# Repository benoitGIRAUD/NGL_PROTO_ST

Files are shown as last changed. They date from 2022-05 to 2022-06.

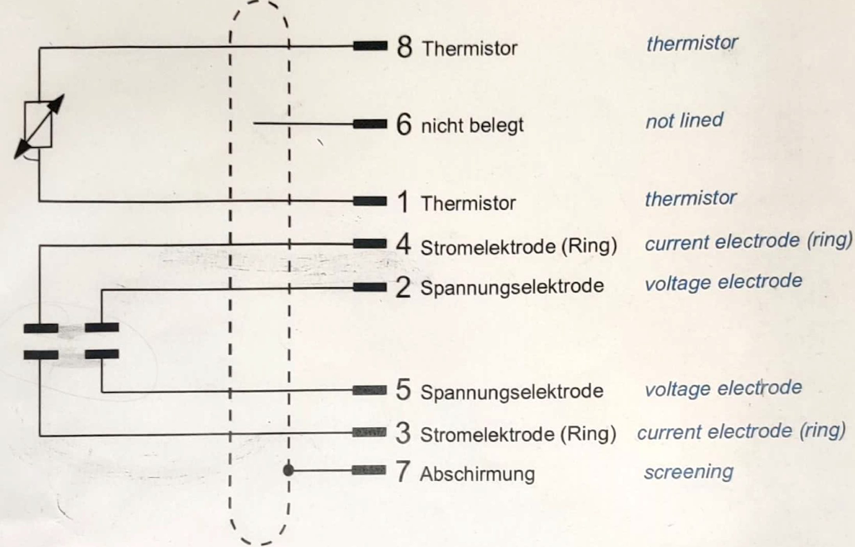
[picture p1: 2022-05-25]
Doc/8DIN.png

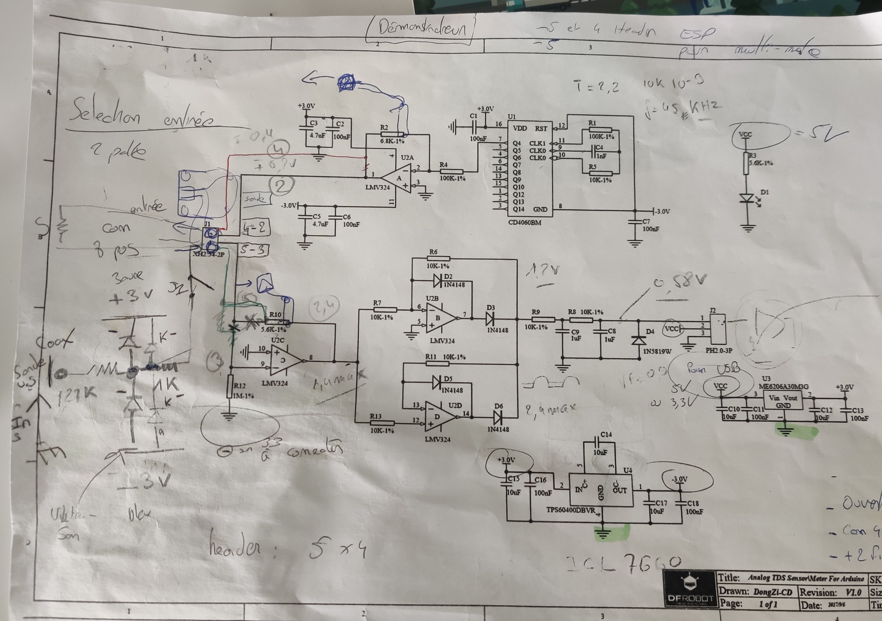
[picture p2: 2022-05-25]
Doc/Schéma_fullAnoté.jpg

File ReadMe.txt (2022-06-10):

2 CHEMIN à rajouter:

LIBNGL
LIBNGL3D

LIBNGL
LIBNGLST
C:\Users\b.giraud-missier.WKS-TH-BE-03\Documents\Git\NGL_PROTO_ST\Lib_NGL_Proto

${LIBNGL}

Mettre le chemin du dossier de Librairie NGL dans LIBNGL:(le début du chemin diffère selon PC)

Ex:
C:\Users\b.giraud-missier.WKS-TH-BE-03\Documents\Git\NGL_Proto\Lib_NGL_Proto\Lib_NGL_Proto.pretty

Et Mettre le chemin du dossier de Librairie NGL dans LIBNGL3D: (le début du chemin diffère selon PC)

Ex:
C:\Users\b.giraud-missier.WKS-TH-BE-03\Documents\Git\NGL_Proto

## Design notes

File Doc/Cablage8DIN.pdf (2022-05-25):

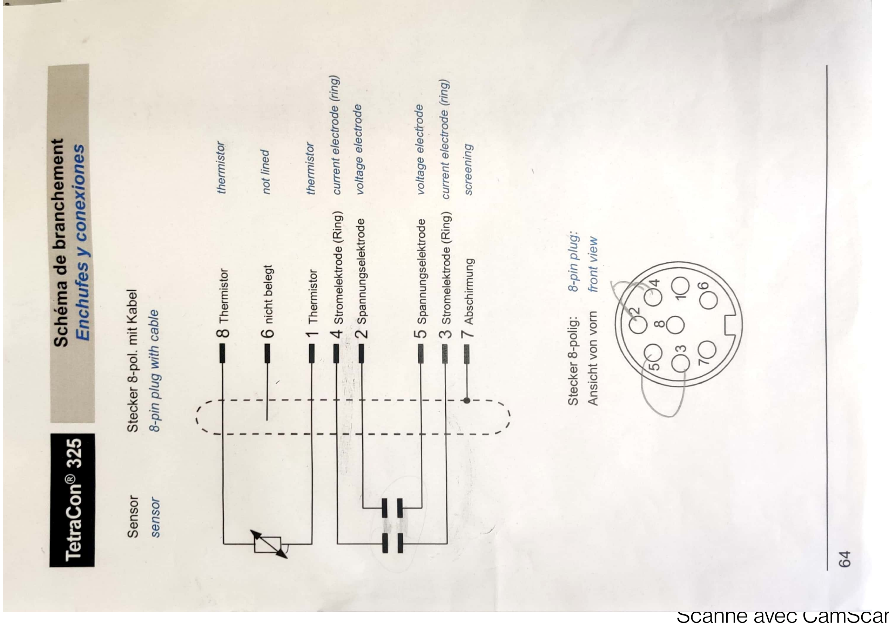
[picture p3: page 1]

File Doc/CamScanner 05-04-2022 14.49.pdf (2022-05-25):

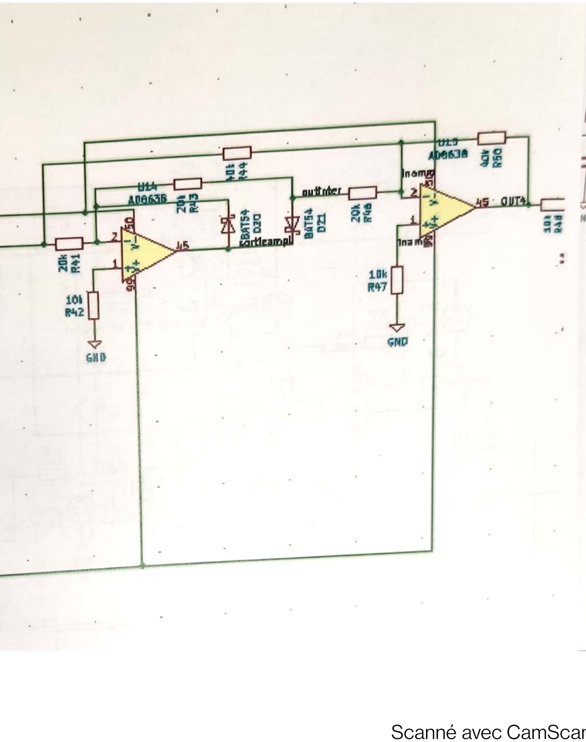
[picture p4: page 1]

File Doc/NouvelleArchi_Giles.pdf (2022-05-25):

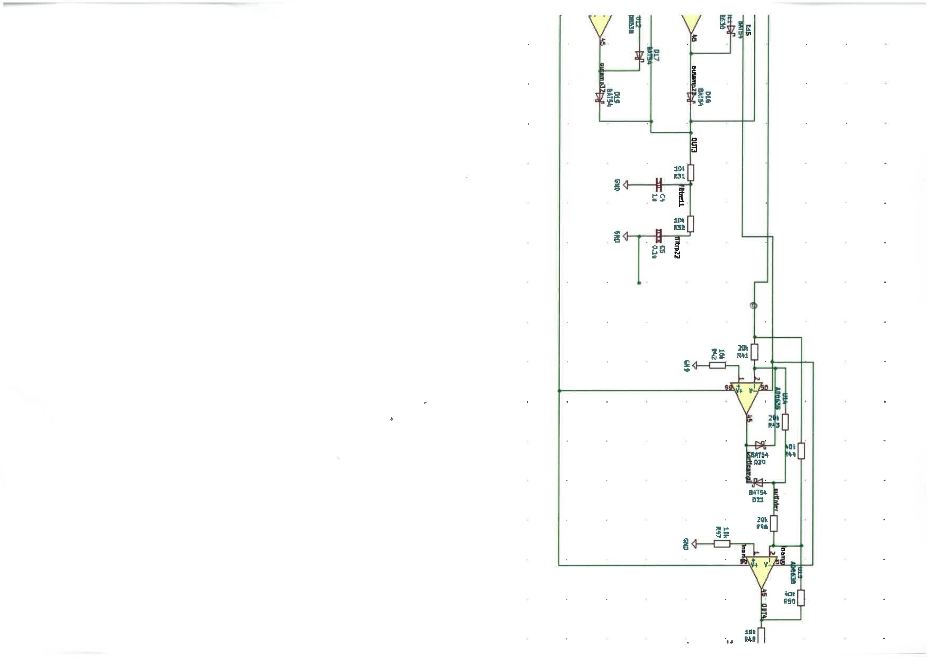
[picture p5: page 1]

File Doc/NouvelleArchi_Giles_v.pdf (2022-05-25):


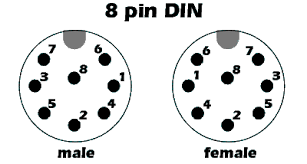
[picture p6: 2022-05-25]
Doc/8DIN_pinout.png

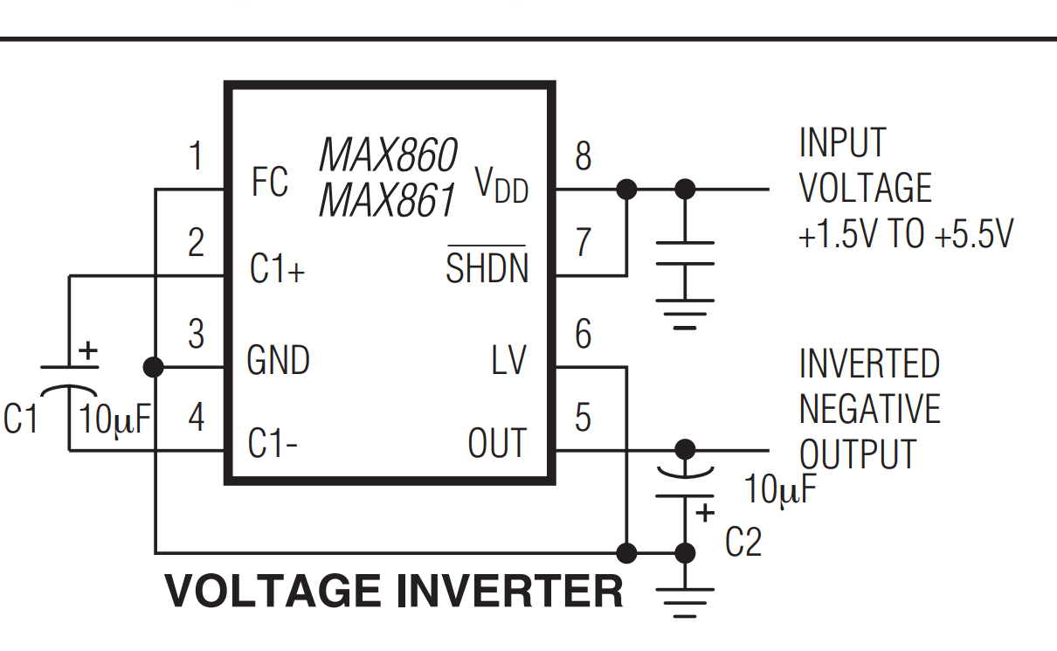
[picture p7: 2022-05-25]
Doc/Inverter.png

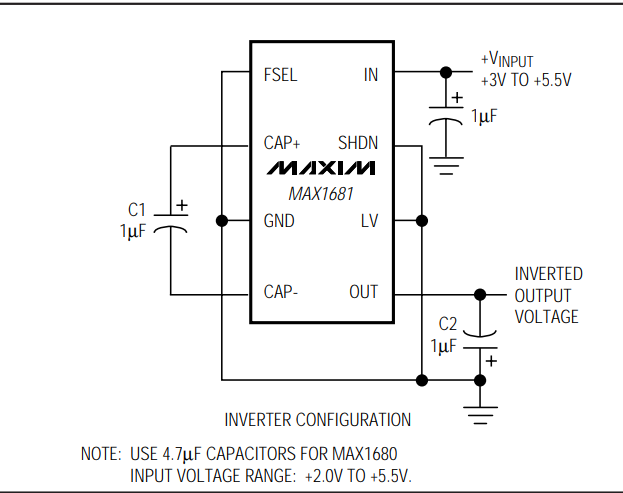
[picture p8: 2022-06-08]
Doc/max1680.PNG

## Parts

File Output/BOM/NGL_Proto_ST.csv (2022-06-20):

Reference | Quantity | Value | Footprint | Datasheet | MPN | MANUFACTURER | MAXIMUM_PACKAGE_HEIGHT | PARTREV | STANDARD | MF | OC_FARNELL | OC_NEWARK | PACKAGE | SUPPLIER | AVAILABILITY | DESCRIPTION | MP | PRICE
B1 B2 B3 B4 | 4 | BUMPER | Lib_NGL_Proto:SJ5003 | https://www.mouser.fr/datasheet/2/1/Bumpon%20Molded%20Shapes%20Colored%20and%20Clear%20Series%20TDS-845047.pdf | SJ5003
BT1 | 1 | 1043 | Lib_NGL_Proto:BAT_1043 | https://www.mouser.fr/datasheet/2/215/1043-745411.pdf | 1043 | Keystone
C15 C17 | 2 | 10uF | Capacitor_SMD:C_0805_2012Metric_Pad1.18x1.45mm_HandSolder | ~
C18 | 1 | 1nF | Capacitor_SMD:C_0805_2012Metric_Pad1.18x1.45mm_HandSolder
C1 C2 C4 C6 C7 C12 C13 C14 C19 C22 C23 C26 C27 C31 C32 | 15 | 100nF | Capacitor_SMD:C_0805_2012Metric_Pad1.18x1.45mm_HandSolder | ~
C30 | 1 | 1uF | Capacitor_SMD:C_0805_2012Metric_Pad1.18x1.45mm_HandSolder | ~
C3 C5 C10 C11 C16 C24 C25 | 7 | 4.7uF | Capacitor_SMD:C_0805_2012Metric_Pad1.18x1.45mm_HandSolder | ~
C8 C9 C20 C21 C28 C29 | 6 | 47uF | Capacitor_SMD:C_0805_2012Metric_Pad1.18x1.45mm_HandSolder | ~
D1 D7 | 2 | LL4148 | Diode_SMD:D_MiniMELF | http://www.vishay.com/docs/85557/ll4148.pdf | LL4148
D10 | 1 | LED_B | LED_THT:LED_D3.0mm | ~
D2 D3 D4 D5 D6 D11 | 6 | D_Schottky | Lib_NGL_Proto:SOT-323_SC-70_Handsoldering | https://www.mouser.fr/datasheet/2/389/cd00278204-1797144.pdf | BAT54WFILMY
J1 | 1 | Conn_01x08_Male | Lib_NGL_Proto:8DIN_THT
J2 | 1 | Conn_01x04_Male | Connector_PinHeader_2.54mm:PinHeader_1x06_P2.54mm_Vertical | ~
J3 | 1 | 227161-2 | Lib_NGL_Proto:TE_5227161-2 | https://www.mouser.fr/datasheet/2/418/8/ENG_CD_227161_AF4-2031034.pdf | 227161-2
J4 | 1 | Conn_01x06_Male | Connector_PinHeader_2.54mm:PinHeader_1x06_P2.54mm_Vertical | ~
J5 | 1 | Conn_01x04_Male | Connector_PinHeader_2.54mm:PinHeader_1x04_P2.54mm_Vertical | ~
J6 | 1 | Conn_01x03_Male | Connector_PinHeader_2.54mm:PinHeader_1x03_P2.54mm_Vertical | ~
JP1 JP2 JP4 JP8 JP9 JP10 | 6 | Jumper_NC_Small | Connector_PinHeader_2.54mm:PinHeader_1x02_P2.54mm_Vertical | ~
M1 | 1 | ROB-08449 | Connector_PinHeader_2.54mm:PinHeader_1x02_P2.54mm_Vertical | https://www.mouser.fr/datasheet/2/813/B1034_FL45_00_015-2490184.pdf |  |  |  |  |  | Jinlong Machinery
POT1 | 1 | 50k | Lib_NGL_Proto:3224X-1-502E | https://www.mouser.fr/datasheet/2/54/3224-776900.pdf
R1 | 1 | 300K | Resistor_SMD:R_0805_2012Metric_Pad1.20x1.40mm_HandSolder | ~
R10 | 1 | 590 | Resistor_SMD:R_0805_2012Metric_Pad1.20x1.40mm_HandSolder | ~
R5 R12 R34 R35 | 4 | 1M | Resistor_SMD:R_0805_2012Metric_Pad1.20x1.40mm_HandSolder | ~
R14 | 1 | 1K | Resistor_SMD:R_0805_2012Metric_Pad1.20x1.40mm_HandSolder | ~
R15 | 1 | 43R | Resistor_SMD:R_0805_2012Metric_Pad1.20x1.40mm_HandSolder | ~
R17 R18 R19 R20 R21 | 5 | 4.7K | Resistor_SMD:R_0805_2012Metric_Pad1.20x1.40mm_HandSolder | ~
R2 | 1 | 348R | Resistor_SMD:R_0805_2012Metric_Pad1.20x1.40mm_HandSolder | ~
R6 R7 R16 R23 R27 R29 | 6 | 20K | Resistor_SMD:R_0805_2012Metric_Pad1.20x1.40mm_HandSolder | ~
R22 R25 R28 R31 R52S1 | 5 | 40K | Resistor_SMD:R_0805_2012Metric_Pad1.20x1.40mm_HandSolder | ~
R2P1 R10P1 | 2 | NC | Resistor_SMD:R_0805_2012Metric_Pad1.20x1.40mm_HandSolder | ~
R3 | 1 | 127K | Resistor_SMD:R_0805_2012Metric_Pad1.20x1.40mm_HandSolder | ~
R39 | 1 | 0R | Resistor_SMD:R_0805_2012Metric_Pad1.20x1.40mm_HandSolder | ~
R4 | 1 | 100K | Resistor_SMD:R_0805_2012Metric_Pad1.20x1.40mm_HandSolder | ~
R8 R9 R11 R13 R24 R26 R30 R32 R33 R36 R37 | 11 | 10K | Resistor_SMD:R_0805_2012Metric_Pad1.20x1.40mm_HandSolder | ~
S1 | 1 | 1101M2S3CQE2 | Lib_NGL_Proto:SW_1101M2S3CQE2 | https://docs.rs-online.com/eaa8/0900766b800993da.pdf |  | CnK
SB1 SB3 SB4 | 3 | SB | Jumper:SolderJumper-2_P1.3mm_Open_RoundedPad1.0x1.5mm | ~
SB2 | 1 | SolderJumper_2_Bridged | Jumper:SolderJumper-2_P1.3mm_Open_RoundedPad1.0x1.5mm | ~
SW3 SW4 | 2 | SW_Push | Lib_NGL_Proto:3-1825910-5 | https://docs.rs-online.com/7f47/0900766b8144c664.pdf | 3-1825910-5
T1 | 1 | RU1C002UNTCL | Lib_NGL_ST:RU1C002UNTCL | https://www.mouser.fr/datasheet/2/348/ru1c002untcl-e-1873370.pdf
TP1 | 1 | IN | Connector_PinHeader_2.54mm:PinHeader_1x01_P2.54mm_Vertical | ~
TP11 | 1 | OUT_DIFF | Connector_PinHeader_2.54mm:PinHeader_1x01_P2.54mm_Vertical | ~
TP12 | 1 | RECT_DIFF | Connector_PinHeader_2.54mm:PinHeader_1x01_P2.54mm_Vertical | ~
TP15 | 1 | SDO | Connector_PinHeader_2.54mm:PinHeader_1x01_P2.54mm_Vertical | ~
TP2 | 1 | IN_ADC | Connector_PinHeader_2.54mm:PinHeader_1x01_P2.54mm_Vertical | ~
TP3 | 1 | OUT | Connector_PinHeader_2.54mm:PinHeader_1x01_P2.54mm_Vertical | ~
TP4 | 1 | IN_ADC_DIFF | Connector_PinHeader_2.54mm:PinHeader_1x01_P2.54mm_Vertical | ~
TP5 | 1 | RECT | Connector_PinHeader_2.54mm:PinHeader_1x01_P2.54mm_Vertical | ~
TP6 | 1 | CLK_GEN | TestPoint:TestPoint_Pad_D3.0mm | ~
TP7 | 1 | +3.3V | Connector_PinHeader_2.54mm:PinHeader_1x01_P2.54mm_Vertical | ~
TP8 | 1 | -3.3V | Connector_PinHeader_2.54mm:PinHeader_1x01_P2.54mm_Vertical | ~
TP9 TP10 TP13 TP14 | 4 | GND | Connector_PinHeader_2.54mm:PinHeader_1x01_P2.54mm_Vertical | ~
TPP10 | 1 | TestPointPad | TestPoint:TestPoint_Pad_D3.0mm | ~
TPP2 | 1 | +BATT | TestPoint:TestPoint_Pad_D3.0mm | ~
TPP4 | 1 | GND | TestPoint:TestPoint_Pad_4.0x4.0mm | ~
TPP6 | 1 | TestPoint | TestPoint:TestPoint_Pad_D3.0mm | ~
U1 U2 U8 | 3 | AD8639 | Lib_NGL_Proto:ADA4522-2ARZ | https://www.analog.com/static/imported-files/data_sheets/ADA4075-2.pdf | AD8639
U10 | 1 | 10K | Lib_NGL_ST:max5481eud&plus_T | https://www.mouser.fr/datasheet/2/256/MAX5483-1513459.pdf | MAX5481EUD+
U11 | 1 | 20k | Lib_NGL_ST:SOP50P490X110-10N | https://www.analog.com/media/en/technical-documentation/data-sheets/AD5270_5271.pdf | AD5270BRMZ-20 |  |  |  |  |  |  | 52R8111 |  | Analog Devices
U3 | 1 | MAX922CSAT | Lib_NGL_Proto:SOIC127P600X175-8N | https://docs.rs-online.com/cb30/0900766b812a5f89.pdf | MAX922CSAT
U4 | 1 | ESP32-WROOM-32D-N16 | Lib_NGL_Proto:MODULE_ESP32-WROOM-32D | https://www.mouser.fr/datasheet/2/891/esp32_wroom_32d_esp32_wroom_32u_datasheet_en-1365844.pdf | ESP32-WROOM-32D-N16 | Espressif Systems | 3.25mm | 1.4 | Manufacturer Recommendations
U5 | 1 | LD29080PT33R | Lib_NGL_ST:DPAK114P990X239-6N | https://www.mouser.fr/datasheet/2/389/cd00044919-1796076.pdf | LF33CDT-TR |  |  |  |  |  | 2253503 | 26M0226 | DPAK | STMicroelectronics
U6 | 1 | MAX1680ESA+T | Lib_NGL_ST:SOIC127P600X175-8N | https://www.mouser.fr/datasheet/2/256/MAX1680-MAX1681-1515321.pdf |  |  |  | 0 | IPC-7351B | Maxim Integrated |  |  | SOIC-8 Maxim Integrated |  | Unavailable | Charge Pump INV/STPUP -2V to -5.5V/5V to 11V 125mA 8-Pin SOIC N | MAX1680ESA+T | None
U7 | 1 | AD620 | Lib_NGL_Proto:SOIC127P600X175-8N | https://www.analog.com/media/en/technical-documentation/data-sheets/AD620.pdf | AD620
U9 | 1 | MCP3426A0-E_SN | SOIC127P600X175-8N | https://docs.rs-online.com/447c/0900766b81380b5e.pdf | MCP3426A0-E_SN

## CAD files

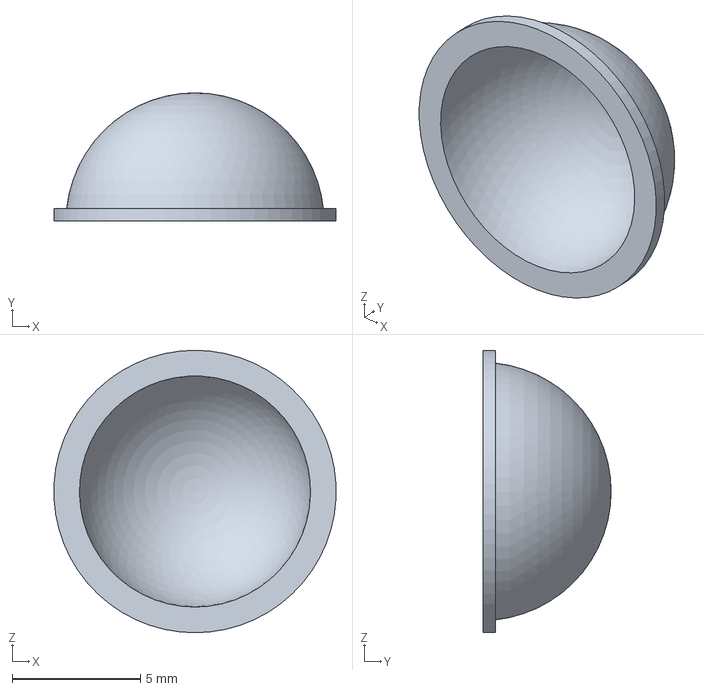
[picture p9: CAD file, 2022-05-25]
Lib_NGL_Proto/Bumpon SG5003.stp
11.0 x 5.00 x 11.0 mm

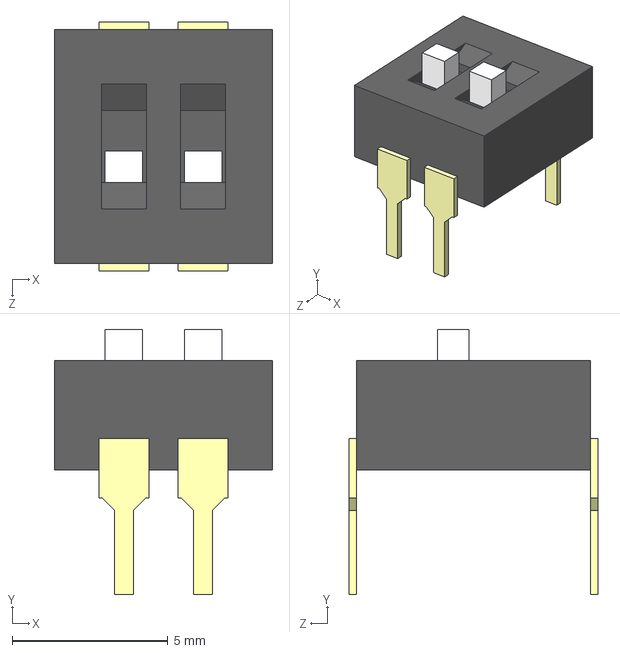
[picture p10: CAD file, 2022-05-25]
Lib_NGL_Proto/A6TN_2104.step
7.00 x 8.50 x 8.00 mm

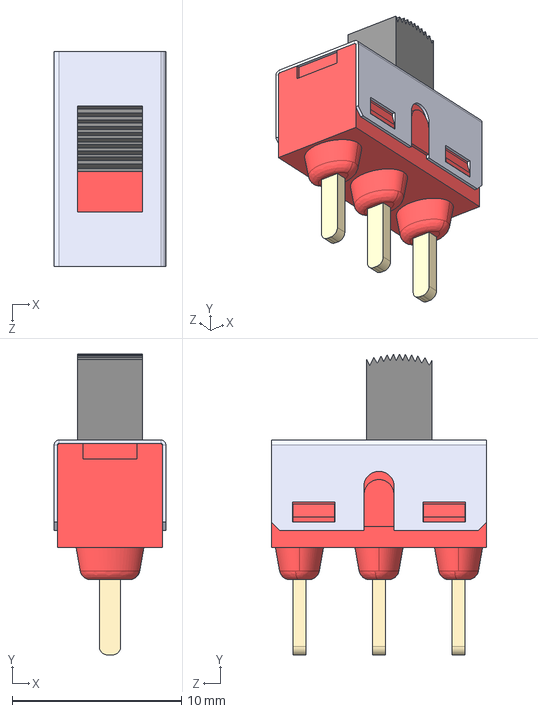
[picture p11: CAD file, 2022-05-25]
Lib_NGL_Proto/1101M2S3CQE2.step
6.60 x 17.8 x 12.7 mm

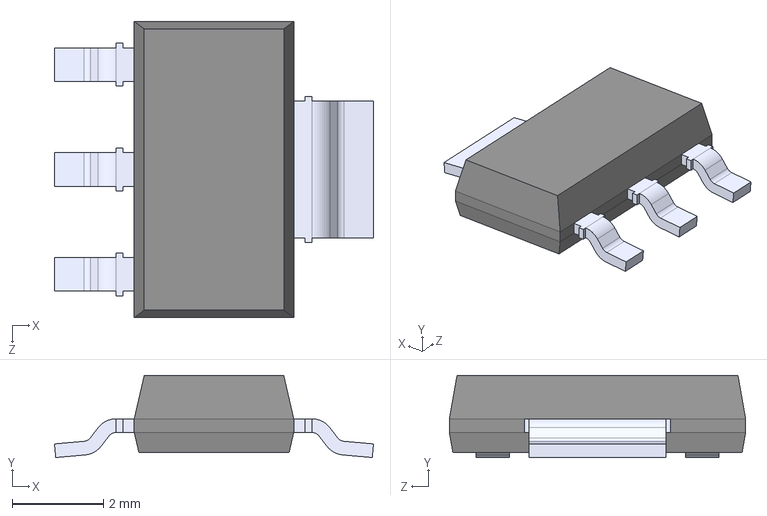
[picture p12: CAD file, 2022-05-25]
Lib_NGL_Proto/NCP1117LPST33T3G.step
7.00 x 1.80 x 6.50 mm

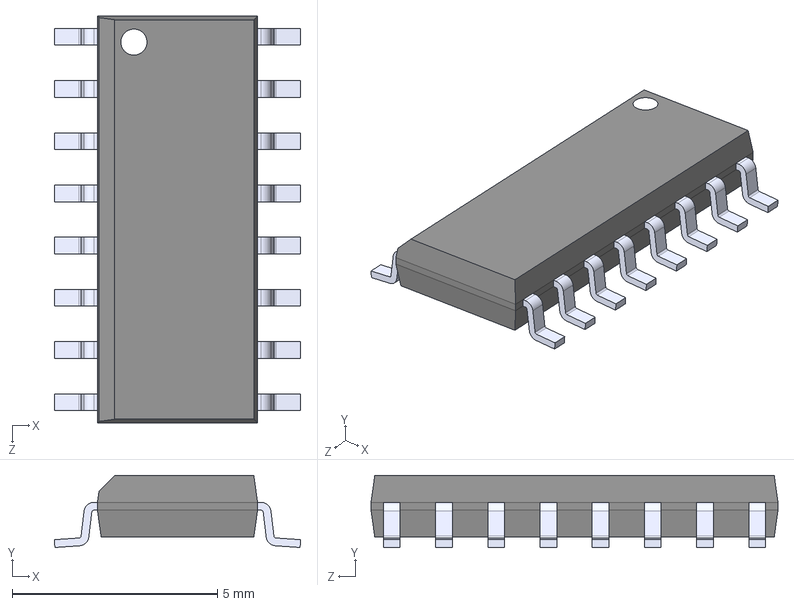
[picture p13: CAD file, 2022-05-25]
Lib_NGL_Proto/CD4060BM96.step
5.99 x 1.75 x 9.91 mm

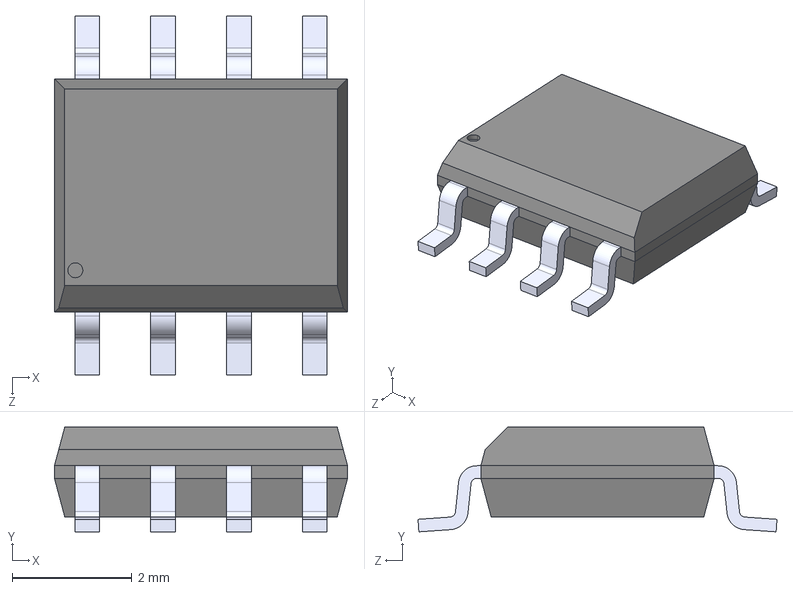
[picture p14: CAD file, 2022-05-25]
Lib_NGL_Proto/AD620ARZ-REEL7-REEL7.step
4.90 x 1.75 x 6.00 mm

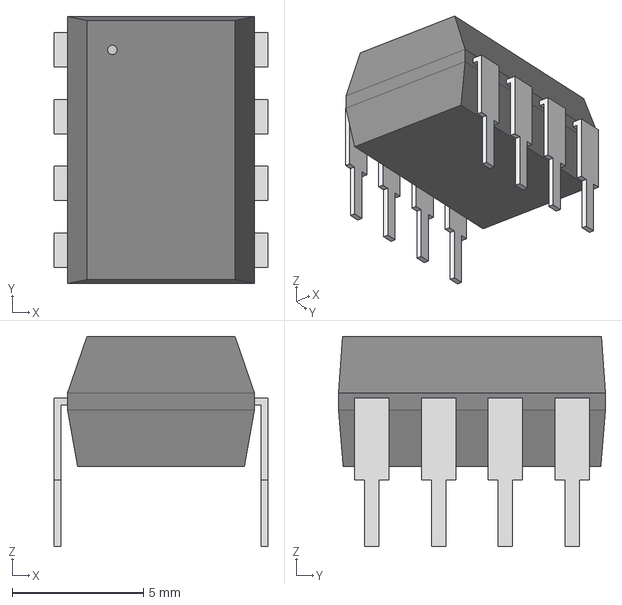
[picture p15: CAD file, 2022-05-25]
Lib_NGL_Proto/PDIP8_300MC_MCH.step
8.13 x 10.2 x 8.00 mm

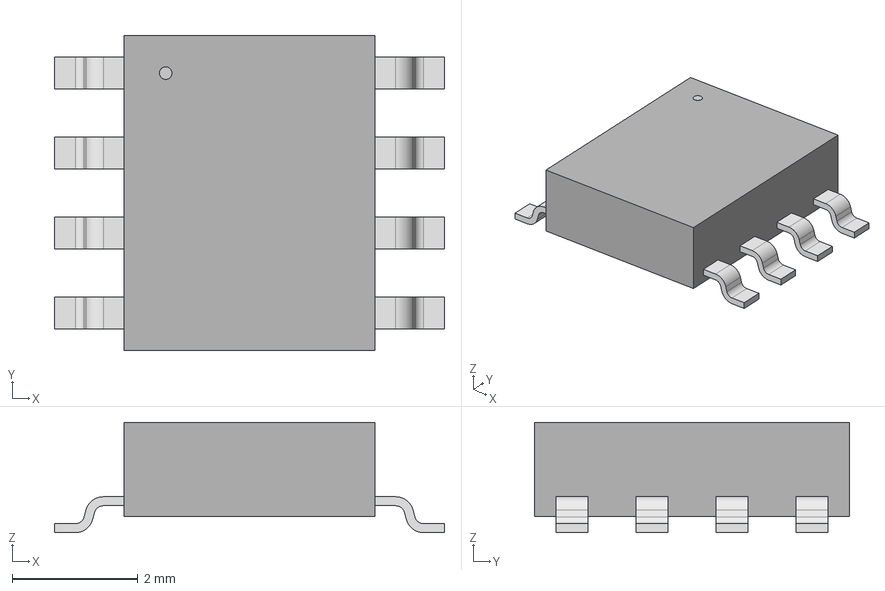
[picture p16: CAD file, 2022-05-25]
Lib_NGL_Proto/R_8_ADI.step
6.20 x 5.00 x 1.75 mm

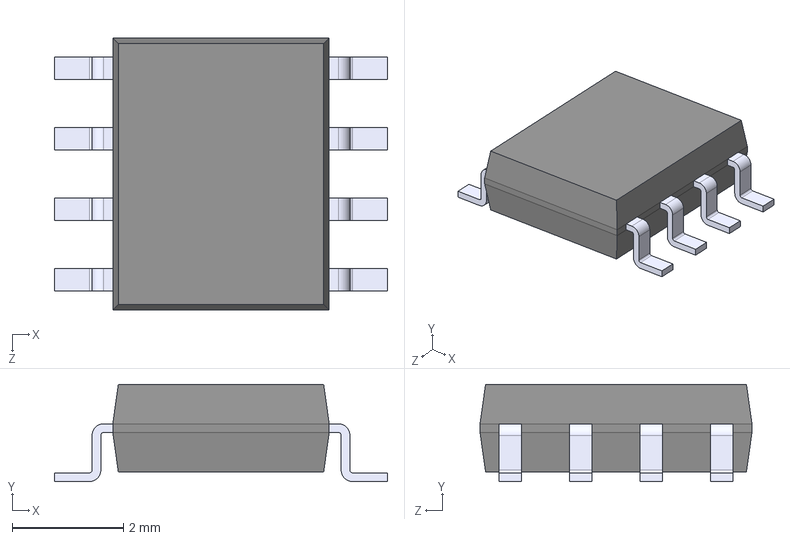
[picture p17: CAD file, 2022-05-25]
Lib_NGL_Proto/MCP3426A0-E_SN.step
6.00 x 1.75 x 4.90 mm

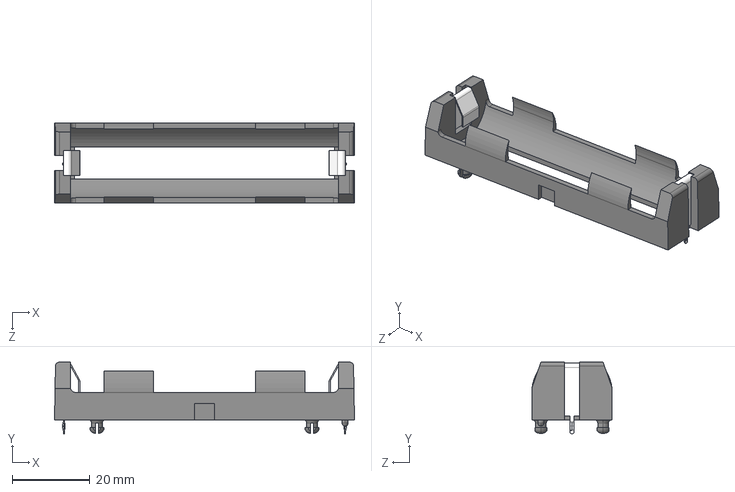
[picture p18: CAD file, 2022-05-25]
Lib_NGL_Proto/1043.step
77.1 x 18.4 x 20.7 mm

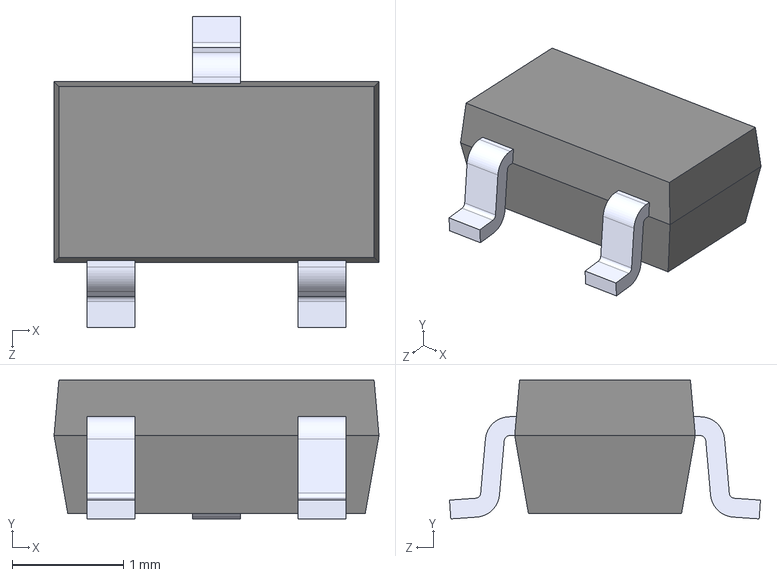
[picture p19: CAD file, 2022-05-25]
Lib_NGL_Proto/SOT23-3P96_237X112L42X44.step
2.93 x 1.25 x 2.80 mm

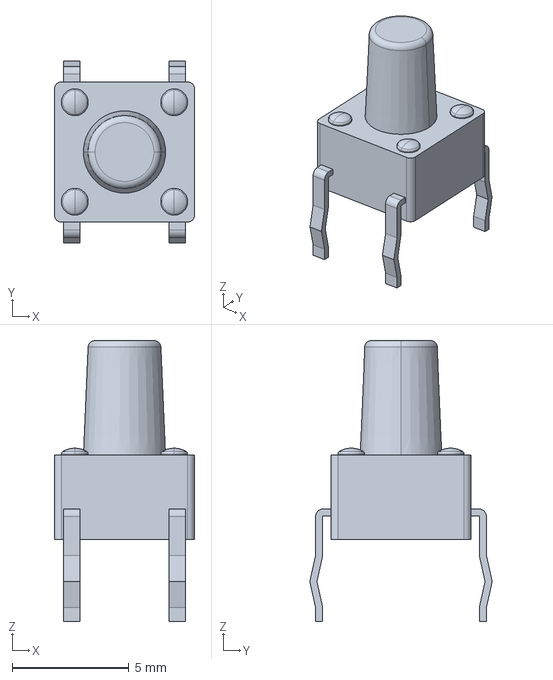
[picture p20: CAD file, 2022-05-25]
Lib_NGL_Proto/c-3-1825910-5-c-3d.stp
5.99 x 7.80 x 12.0 mm

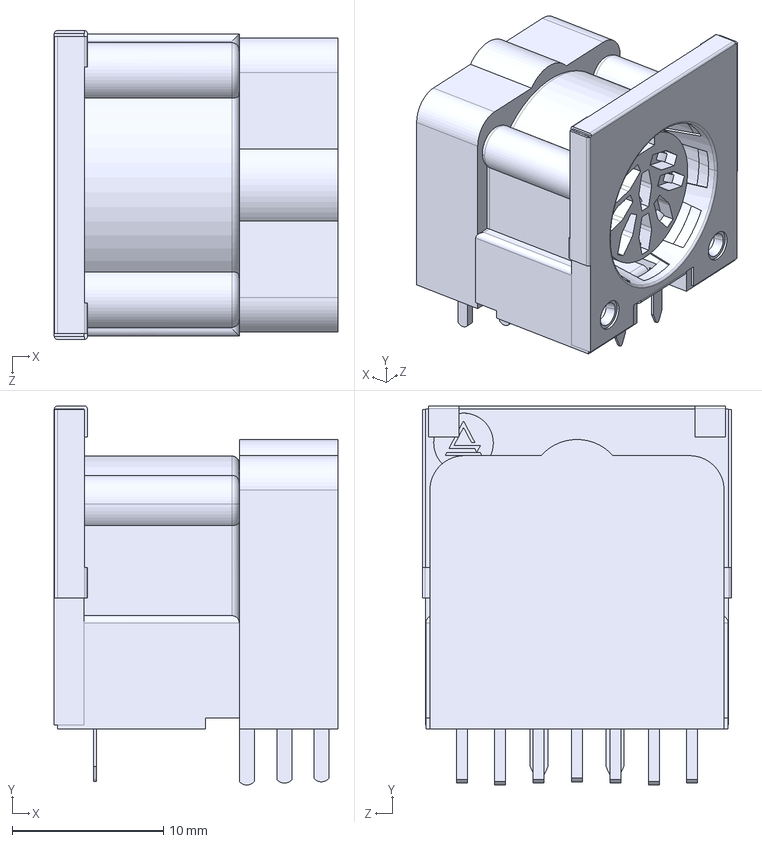
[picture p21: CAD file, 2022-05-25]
Lib_NGL_Proto/62PC8FS--3DModel-STEP-1.STEP
18.7 x 25.0 x 20.4 mm

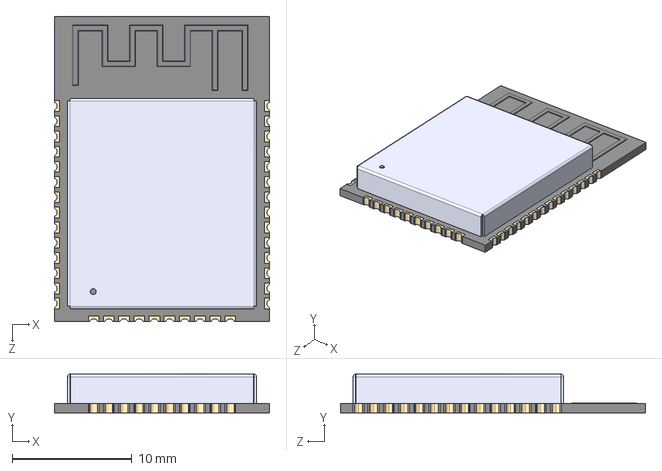
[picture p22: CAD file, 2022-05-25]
Lib_NGL_Proto/ESP32-WROOM-32E__16MB_.step
18.0 x 3.25 x 25.5 mm

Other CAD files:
Lib_NGL_Proto/3224X-1-103E.STEP
Lib_NGL_Proto/5227161-2.step

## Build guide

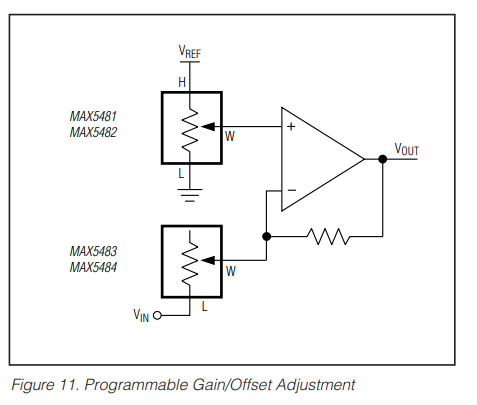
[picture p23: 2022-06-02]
Doc/MAX5481_Montage.PNG

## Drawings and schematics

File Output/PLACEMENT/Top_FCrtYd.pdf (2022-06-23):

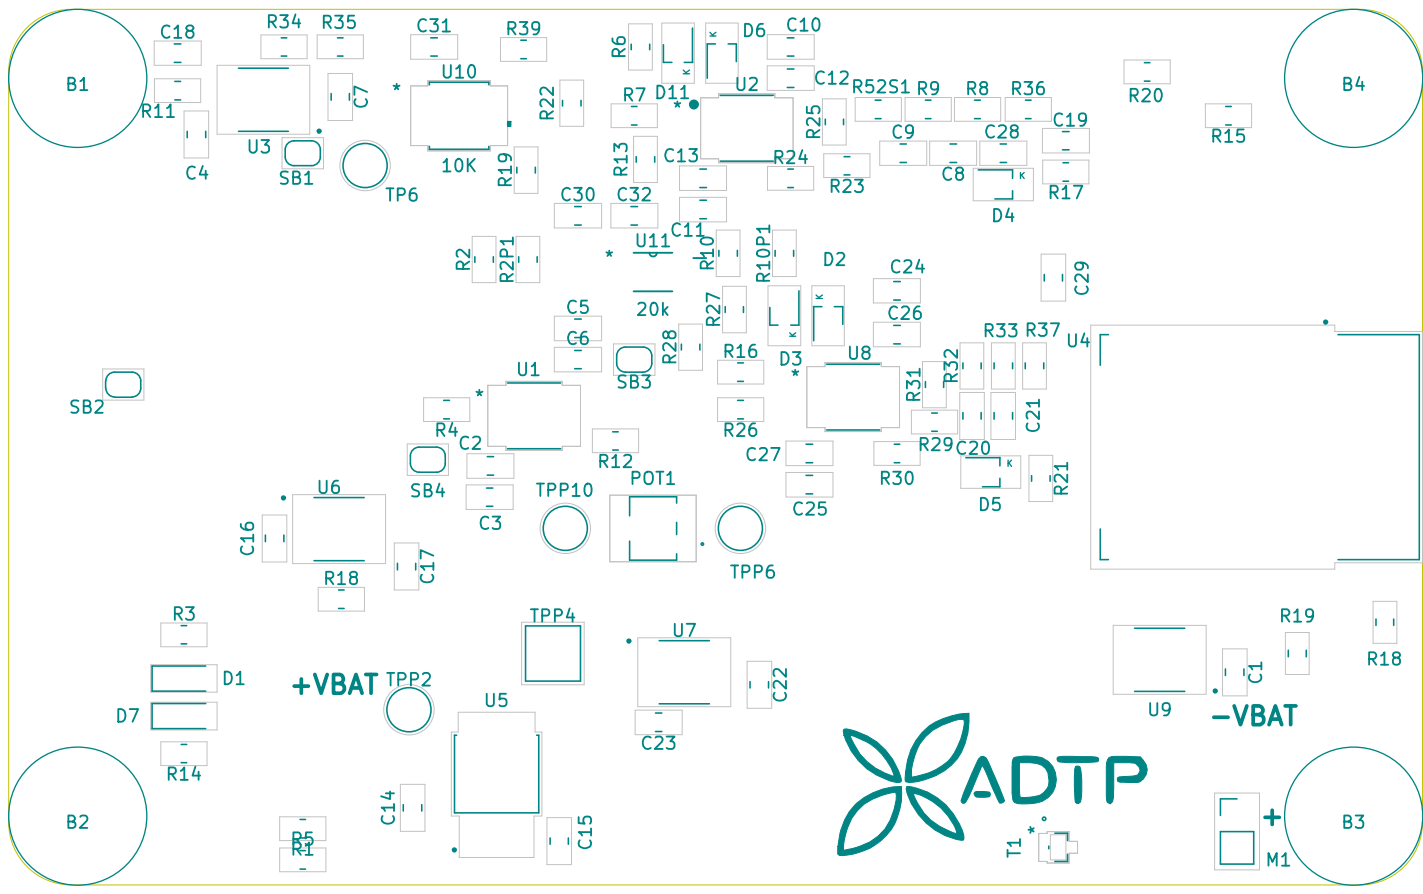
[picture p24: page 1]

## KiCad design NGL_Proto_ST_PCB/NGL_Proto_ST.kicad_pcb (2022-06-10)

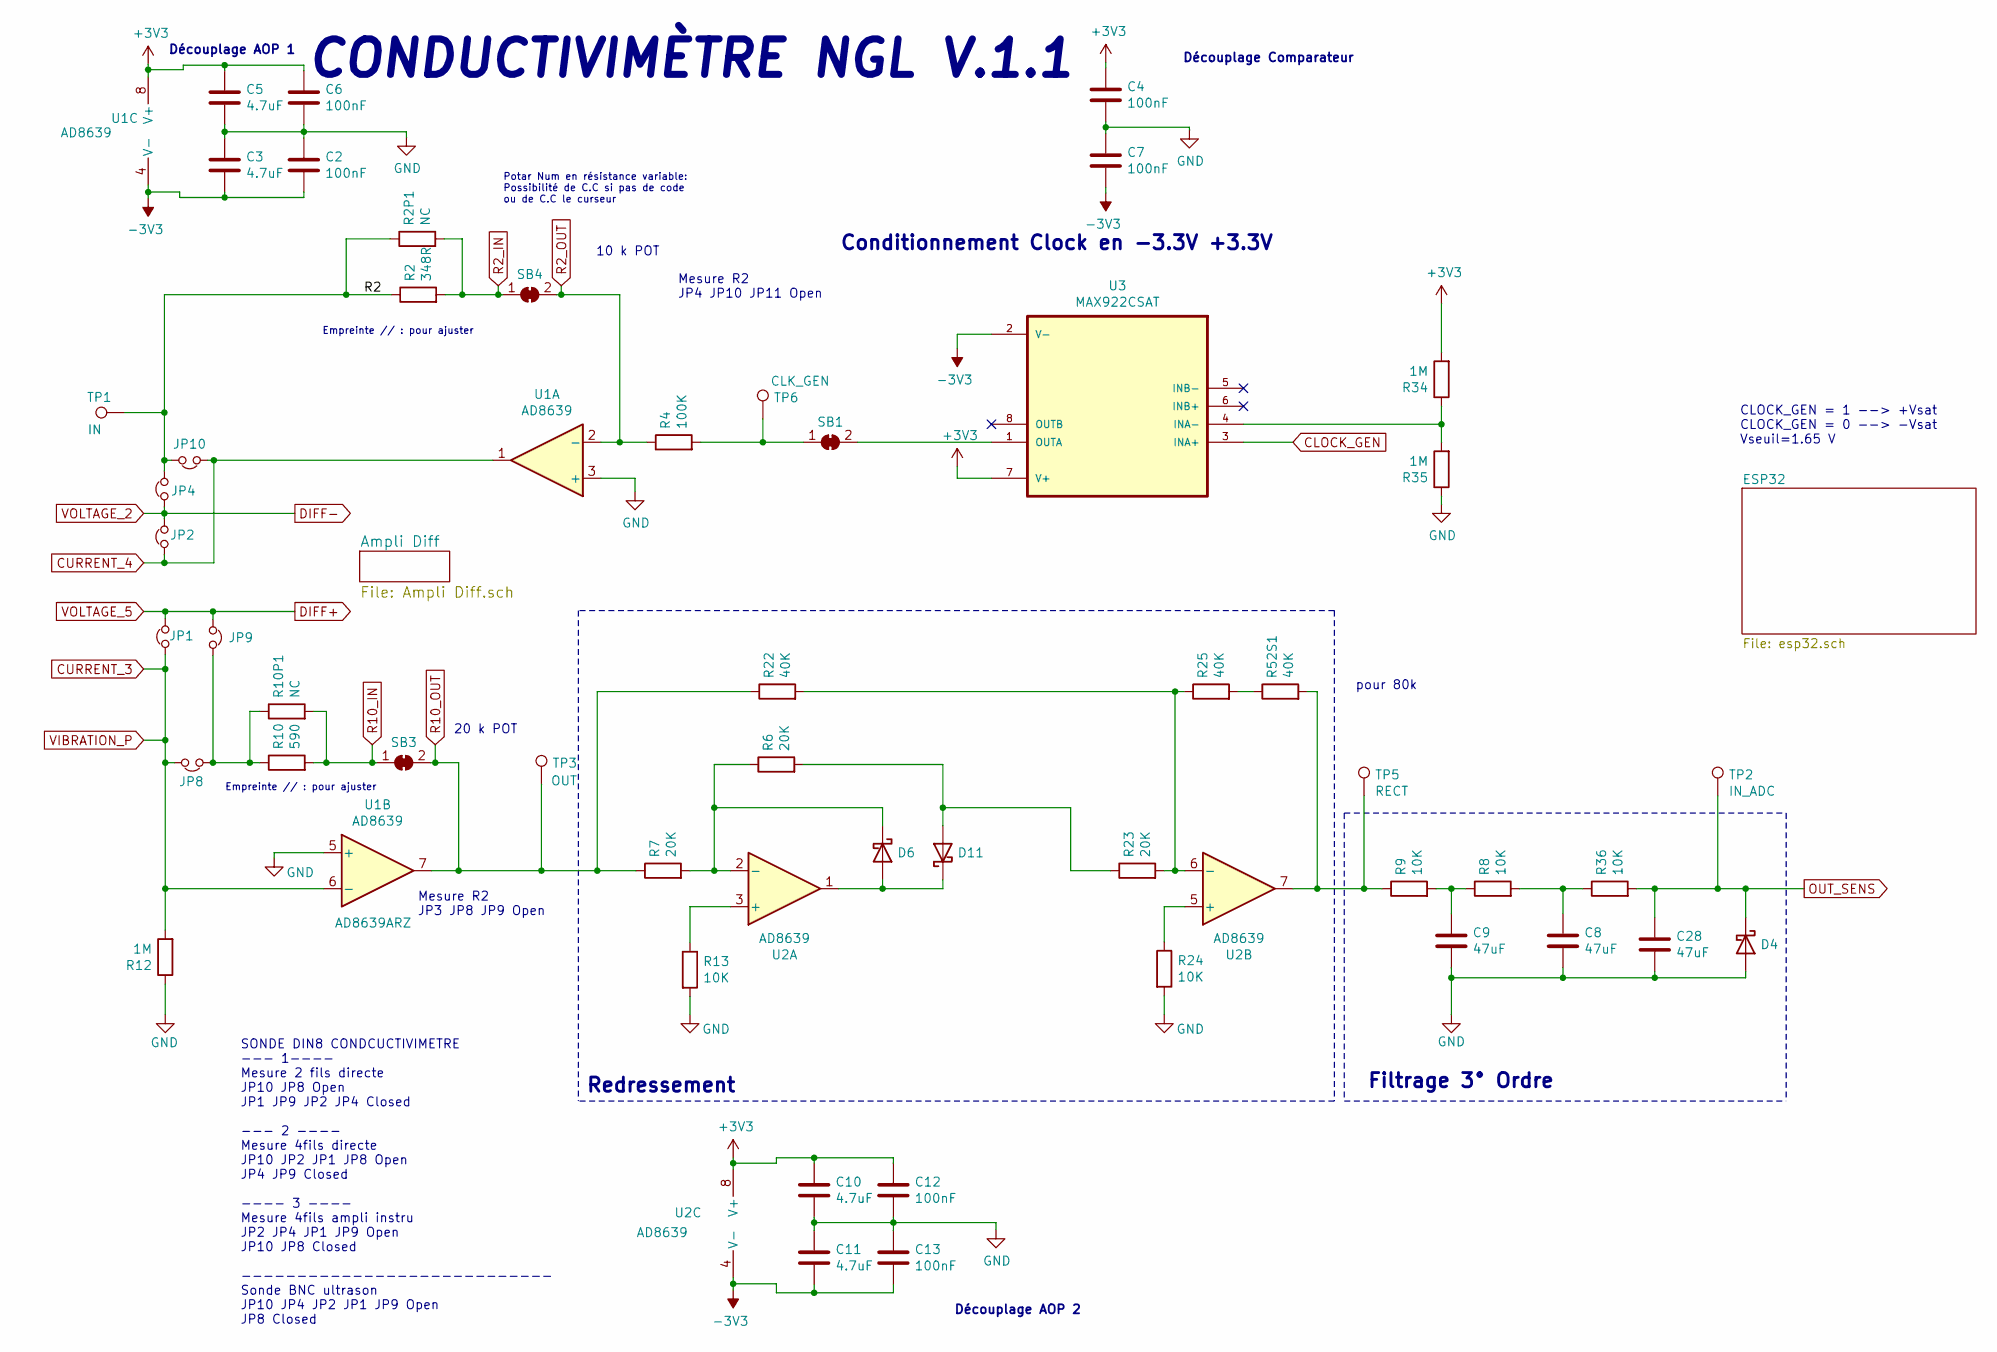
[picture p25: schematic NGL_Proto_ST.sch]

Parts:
C2, C4, C6, C7, C12, C13: 100nF; C_0805_2012Metric_Pad1.18x1.45mm_HandSolder
C3, C5, C10, C11: 4.7uF; C_0805_2012Metric_Pad1.18x1.45mm_HandSolder
C8, C9, C28: 47uF; C_0805_2012Metric_Pad1.18x1.45mm_HandSolder
D4, D6, D11: D_Schottky; SOT-323_SC-70_Handsoldering; MPN BAT54WFILMY
JP1, JP2, JP4, JP8, JP9, JP10: Jumper_NC_Small; PinHeader_1x02_P2.54mm_Vertical
R2: 348R; R_0805_2012Metric_Pad1.20x1.40mm_HandSolder
R2P1, R10P1: NC; R_0805_2012Metric_Pad1.20x1.40mm_HandSolder
R4: 100K; R_0805_2012Metric_Pad1.20x1.40mm_HandSolder
R6, R7, R23: 20K; R_0805_2012Metric_Pad1.20x1.40mm_HandSolder
R8, R9, R13, R24, R36: 10K; R_0805_2012Metric_Pad1.20x1.40mm_HandSolder
R10: 590; R_0805_2012Metric_Pad1.20x1.40mm_HandSolder
R12, R34, R35: 1M; R_0805_2012Metric_Pad1.20x1.40mm_HandSolder
R22, R25, R52S1: 40K; R_0805_2012Metric_Pad1.20x1.40mm_HandSolder
SB1, SB3, SB4: SB; SolderJumper-2_P1.3mm_Open_RoundedPad1.0x1.5mm
TP1: IN; PinHeader_1x01_P2.54mm_Vertical
TP2: IN_ADC; PinHeader_1x01_P2.54mm_Vertical
TP3: OUT; PinHeader_1x01_P2.54mm_Vertical
TP5: RECT; PinHeader_1x01_P2.54mm_Vertical
TP6: CLK_GEN; TestPoint_Pad_D3.0mm
U1, U2: AD8639; ADA4522-2ARZ; MPN AD8639
U3: MAX922CSAT; SOIC127P600X175-8N; MPN MAX922CSAT

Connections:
-3V3: C2.2, C3.2, C7.2, C11.2, C13.2, U1.4 (V-), U2.4 (V-), U3.2 (V-); also elsewhere on the board
/R2: JP4.2, JP10.2, R2.1, R2P1.1, TP1.1
CLOCK_GEN: U3.3 (INA+); also elsewhere on the board
CURRENT_3: JP1.1, JP8.2, R12.2, U1.6 (-); also elsewhere on the board
CURRENT_4: JP2.1, JP10.1, U1.1; also elsewhere on the board
DIFF+: JP1.2, JP9.1; also elsewhere on the board
DIFF-: JP2.2, JP4.1; also elsewhere on the board
unnamed: C8.1, R8.2, R36.1
unnamed: C9.1, R8.1, R9.2
unnamed: D6.1 (K), R6.1, R7.2, U2.2 (-)
unnamed: D6.2 (A), D11.1 (K), U2.1
unnamed: D11.2 (A), R6.2, R23.1
unnamed: JP8.1, JP9.2, R10.1, R10P1.1
unnamed: R4.2, SB1.1 (A), TP6.1
unnamed: R13.1, U2.3 (+)
unnamed: R22.2, R23.2, R25.1, U2.6 (-)
unnamed: R24.1, U2.5 (+)
unnamed: R25.2, R52S1.1
unnamed: R34.1, R35.2, U3.4 (INA-)
unnamed: R9.1, R52S1.2, TP5.1, U2.7
unnamed: SB1.2 (B), U3.1 (OUTA)
OUT_SENS: C28.1, D4.1 (K), R36.2, TP2.1; also elsewhere on the board
R2_IN: R2.2, R2P1.2, SB4.1 (A); also elsewhere on the board
R2_OUT: R4.1, SB4.2 (B), U1.2 (-); also elsewhere on the board
R10_IN: R10.2, R10P1.2, SB3.1 (A); also elsewhere on the board
R10_OUT: R7.1, R22.1, SB3.2 (B), TP3.1, U1.7; also elsewhere on the board

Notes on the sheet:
SONDE DIN8 CONDCUCTIVIMETRE --- 1---- Mesure 2 fils directe JP10 JP8 Open JP1 JP9 JP2 JP4 Closed --- 2 ---- Mesure 4fils directe JP10 JP2 JP1 JP8 Open JP4 JP9 Closed ---- 3 ---- Mesure 4fils ampli instru JP2 JP4 JP1 JP9 Open JP10 JP8 Closed ---------------------------- Sonde BNC ultrason JP10 JP4 J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
Mesure R2 JP4 JP10 JP11 Open
Mesure R2 JP3 JP8 JP9 Open
Découplage AOP 2
Découplage AOP 1
Conditionnement Clock en -3.3V +3.3V
Redressement
Filtrage 3° Ordre
Découplage Comparateur
CLOCK_GEN = 1 --> +Vsat CLOCK_GEN = 0 --> -Vsat Vseuil=1.65 V
Potar Num en résistance variable: Possibilité de C.C si pas de code ou de C.C le curseur
pour 80k
CONDUCTIVIMÈTRE NGL V.1.1
10 k POT
20 k POT
Empreinte // : pour ajuster

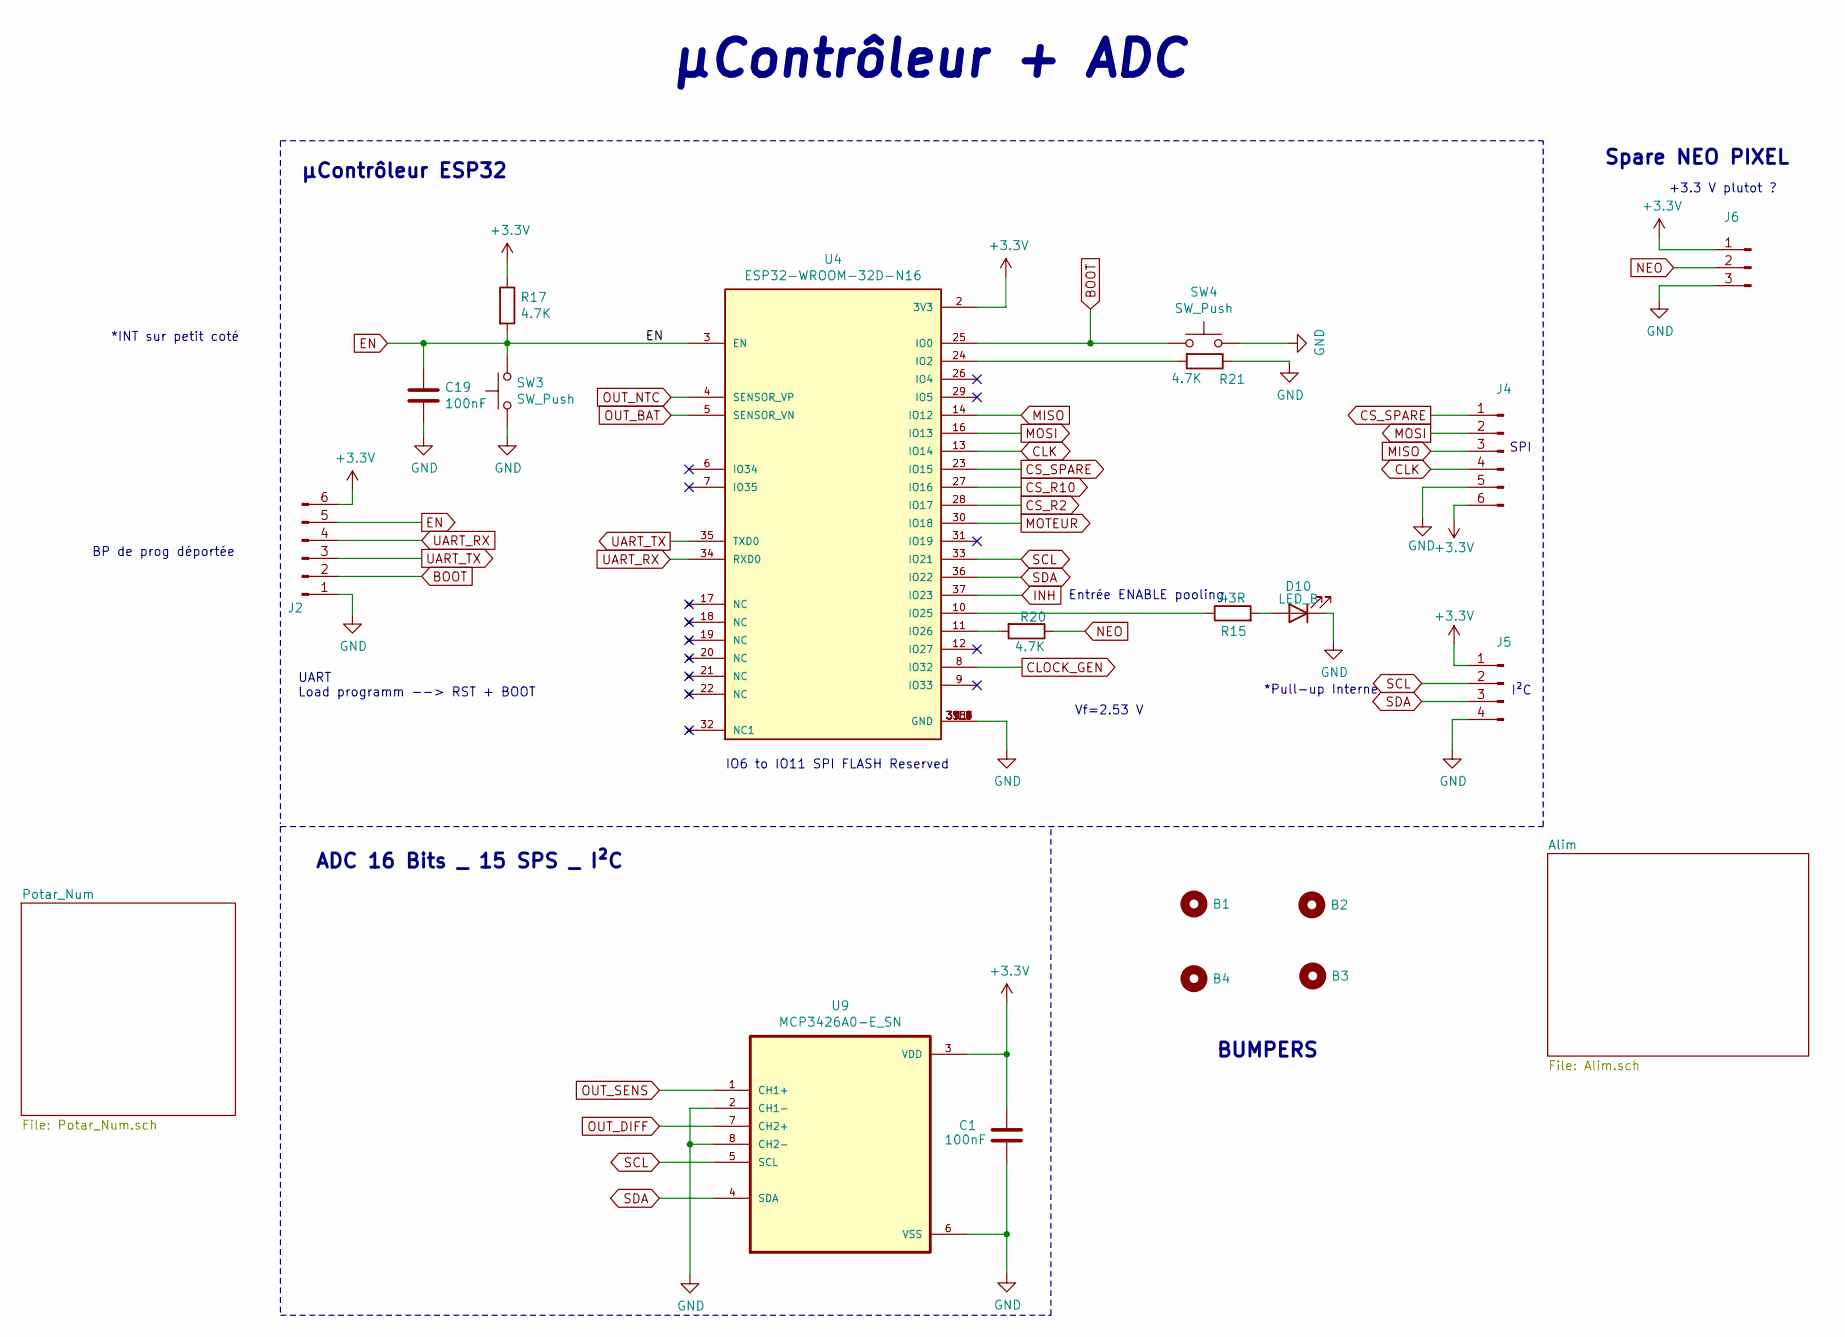
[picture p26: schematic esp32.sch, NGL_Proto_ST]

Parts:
B1, B2, B3, B4: BUMPER; SJ5003; MPN SJ5003
C1, C19: 100nF; C_0805_2012Metric_Pad1.18x1.45mm_HandSolder
D10: LED_B; LED_D3.0mm
J2: Conn_01x04_Male; PinHeader_1x06_P2.54mm_Vertical
J4: Conn_01x06_Male; PinHeader_1x06_P2.54mm_Vertical
J5: Conn_01x04_Male; PinHeader_1x04_P2.54mm_Vertical
J6: Conn_01x03_Male; PinHeader_1x03_P2.54mm_Vertical
R15: 43R; R_0805_2012Metric_Pad1.20x1.40mm_HandSolder
R17, R20, R21: 4.7K; R_0805_2012Metric_Pad1.20x1.40mm_HandSolder
SW3, SW4: SW_Push; 3-1825910-5; MPN 3-1825910-5
U4: ESP32-WROOM-32D-N16; MODULE_ESP32-WROOM-32D; PARTREV 1.4
U9: MCP3426A0-E_SN; SOIC127P600X175-8N; MPN MCP3426A0-E_SN

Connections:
BOOT: J2.2, SW4.1, U4.25 (IO0)
CLK: J4.4, U4.13 (IO14); also elsewhere on the board
CLOCK_GEN: U4.8 (IO32); also elsewhere on the board
CS_R2: U4.28 (IO17); also elsewhere on the board
CS_R10: U4.27 (IO16); also elsewhere on the board
CS_SPARE: J4.1, U4.23 (IO15)
EN: C19.1, J2.5, R17.2, SW3.2, U4.3 (EN)
INH: U4.37 (IO23); also elsewhere on the board
MISO: J4.3, U4.14 (IO12)
MOSI: J4.2, U4.16 (IO13); also elsewhere on the board
MOTEUR: U4.30 (IO18); also elsewhere on the board
NEO: J6.2, R20.1
unnamed: D10.2 (A), R15.2
unnamed: R15.1, U4.10 (IO25)
unnamed: R20.2, U4.11 (IO26)
unnamed: R21.2, U4.24 (IO2)
OUT_BAT: U4.5 (SENSOR_VN); also elsewhere on the board
OUT_DIFF: U9.7 (CH2+); also elsewhere on the board
OUT_NTC: U4.4 (SENSOR_VP); also elsewhere on the board
OUT_SENS: U9.1 (CH1+); also elsewhere on the board
SCL: J5.2, U4.33 (IO21), U9.5 (SCL)
SDA: J5.3, U4.36 (IO22), U9.4 (SDA)

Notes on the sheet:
IO6 to IO11 SPI FLASH Reserved
UART Load programm --> RST + BOOT
SPI
I²C
μContrôleur ESP32
Spare NEO PIXEL
ADC 16 Bits _ 15 SPS _ I²C
BUMPERS
+3.3 V plutot ?
Vf=2.53 V
μContrôleur + ADC
*Pull-up Interne
*INT sur petit coté
Entrée ENABLE pooling
BP de prog déportée

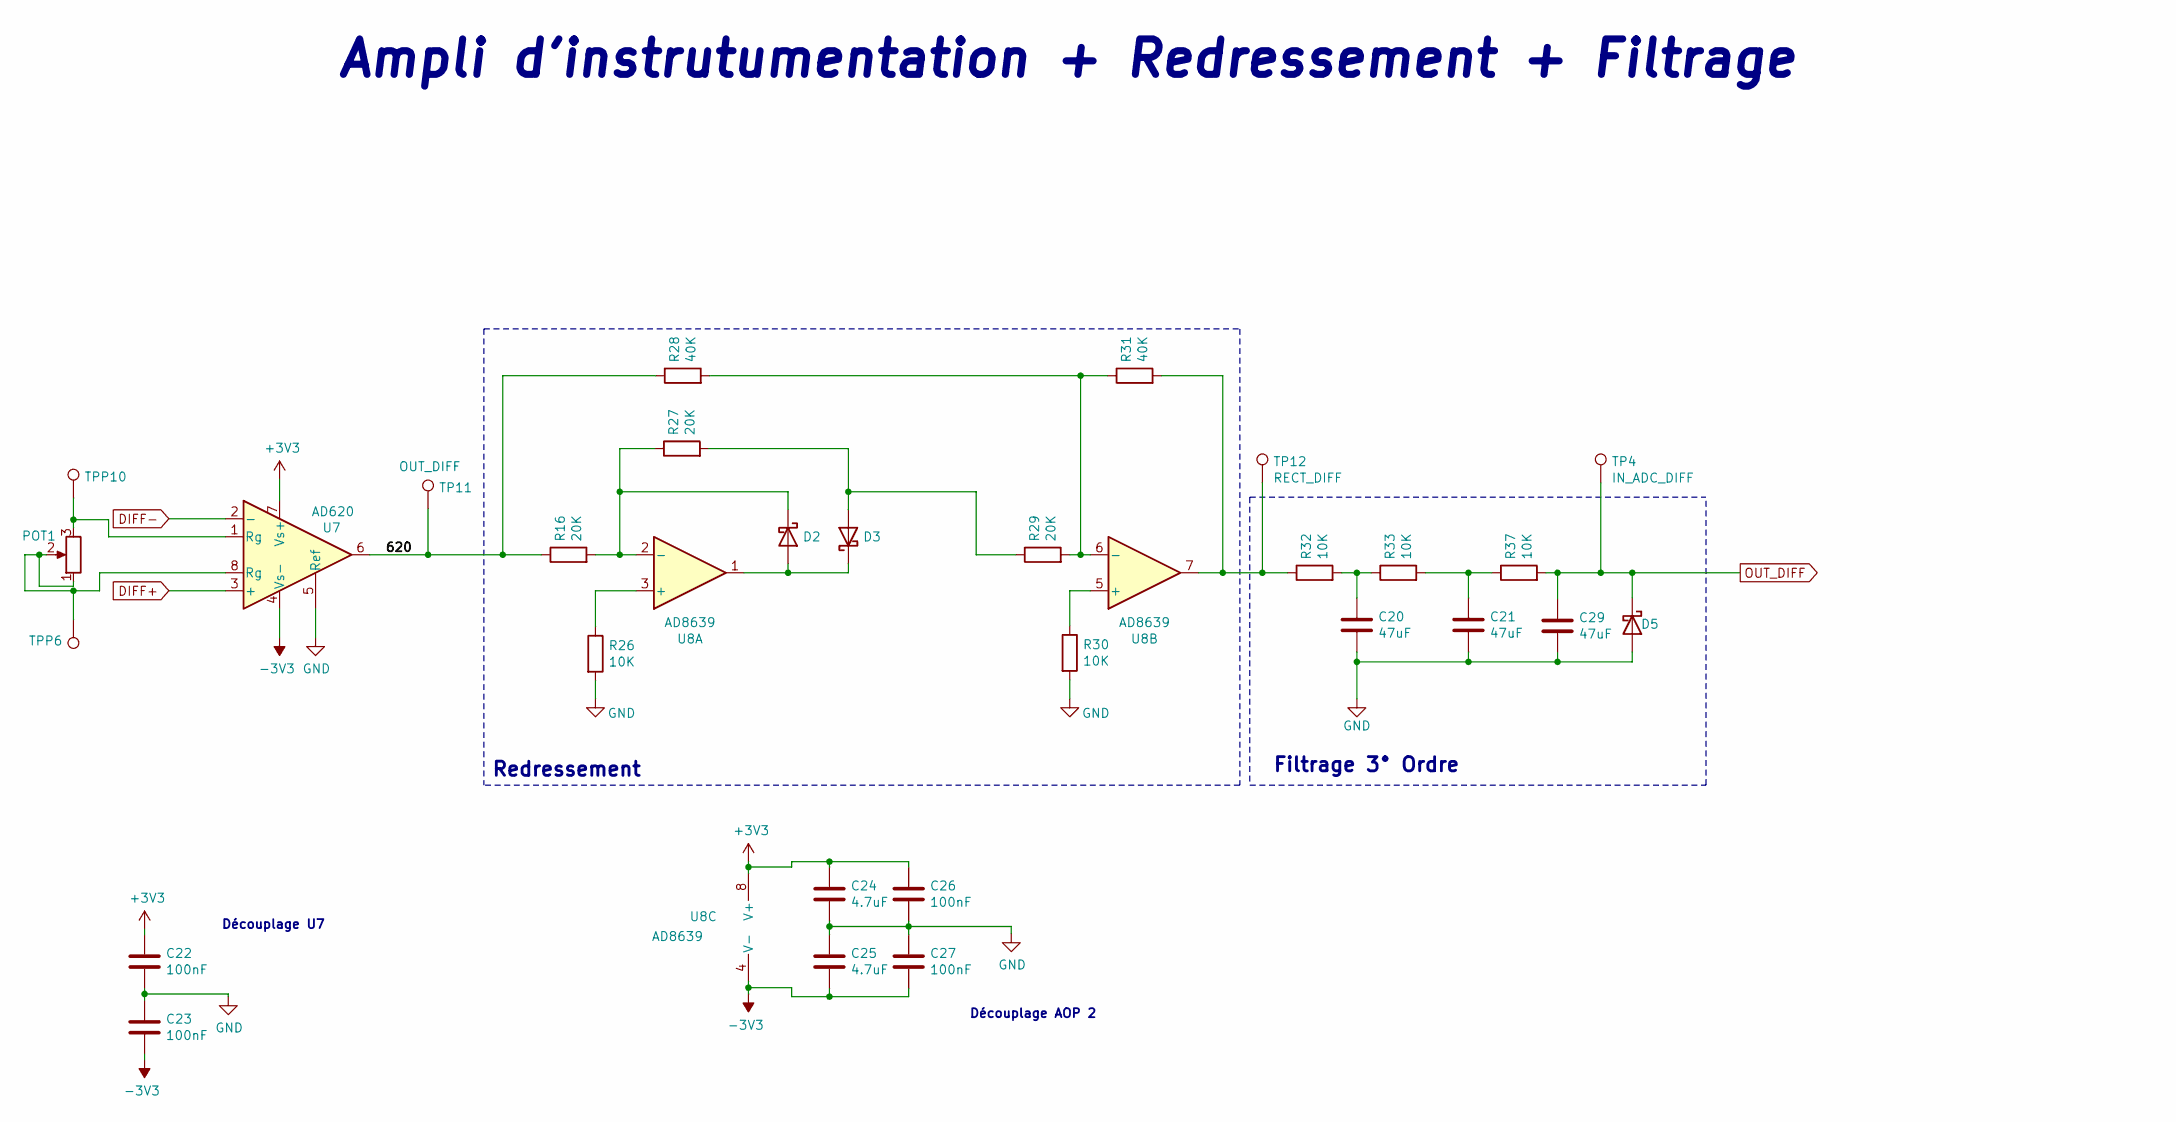
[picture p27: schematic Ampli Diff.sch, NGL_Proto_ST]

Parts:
C20, C21, C29: 47uF; C_0805_2012Metric_Pad1.18x1.45mm_HandSolder
C22, C23, C26, C27: 100nF; C_0805_2012Metric_Pad1.18x1.45mm_HandSolder
C24, C25: 4.7uF; C_0805_2012Metric_Pad1.18x1.45mm_HandSolder
D2, D3, D5: D_Schottky; SOT-323_SC-70_Handsoldering; MPN BAT54WFILMY
POT1: 50k; 3224X-1-502E
R16, R27, R29: 20K; R_0805_2012Metric_Pad1.20x1.40mm_HandSolder
R26, R30, R32, R33, R37: 10K; R_0805_2012Metric_Pad1.20x1.40mm_HandSolder
R28, R31: 40K; R_0805_2012Metric_Pad1.20x1.40mm_HandSolder
TP4: IN_ADC_DIFF; PinHeader_1x01_P2.54mm_Vertical
TP11: OUT_DIFF; PinHeader_1x01_P2.54mm_Vertical
TP12: RECT_DIFF; PinHeader_1x01_P2.54mm_Vertical
TPP6: TestPoint; TestPoint_Pad_D3.0mm
TPP10: TestPointPad; TestPoint_Pad_D3.0mm
U7: AD620; SOIC127P600X175-8N; MPN AD620
U8: AD8639; ADA4522-2ARZ; MPN AD8639

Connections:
-3V3: C23.2, C25.2, C27.2, U7.4 (Vs-), U8.4 (V-); also elsewhere on the board
/Ampli Diff/620: R16.1, R28.1, TP11.1, U7.6
DIFF+: U7.3 (+); also elsewhere on the board
DIFF-: U7.2 (-); also elsewhere on the board
unnamed: C20.1, R32.2, R33.1
unnamed: C21.1, R33.2, R37.1
unnamed: D2.1 (K), R16.2, R27.1, U8.2 (-)
unnamed: D2.2 (A), D3.1 (K), U8.1
unnamed: D3.2 (A), R27.2, R29.1
unnamed: POT1.1, POT1.2, TPP6.1, U7.8 (Rg)
unnamed: POT1.3, TPP10.1, U7.1 (Rg)
unnamed: R26.1, U8.3 (+)
unnamed: R28.2, R29.2, R31.1, U8.6 (-)
unnamed: R30.1, U8.5 (+)
unnamed: R31.2, R32.1, TP12.1, U8.7
OUT_DIFF: C29.1, D5.1 (K), R37.2, TP4.1; also elsewhere on the board

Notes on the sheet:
Redressement
Filtrage 3° Ordre
Ampli d'instrutumentation + Redressement + Filtrage
Découplage U7
Découplage AOP 2

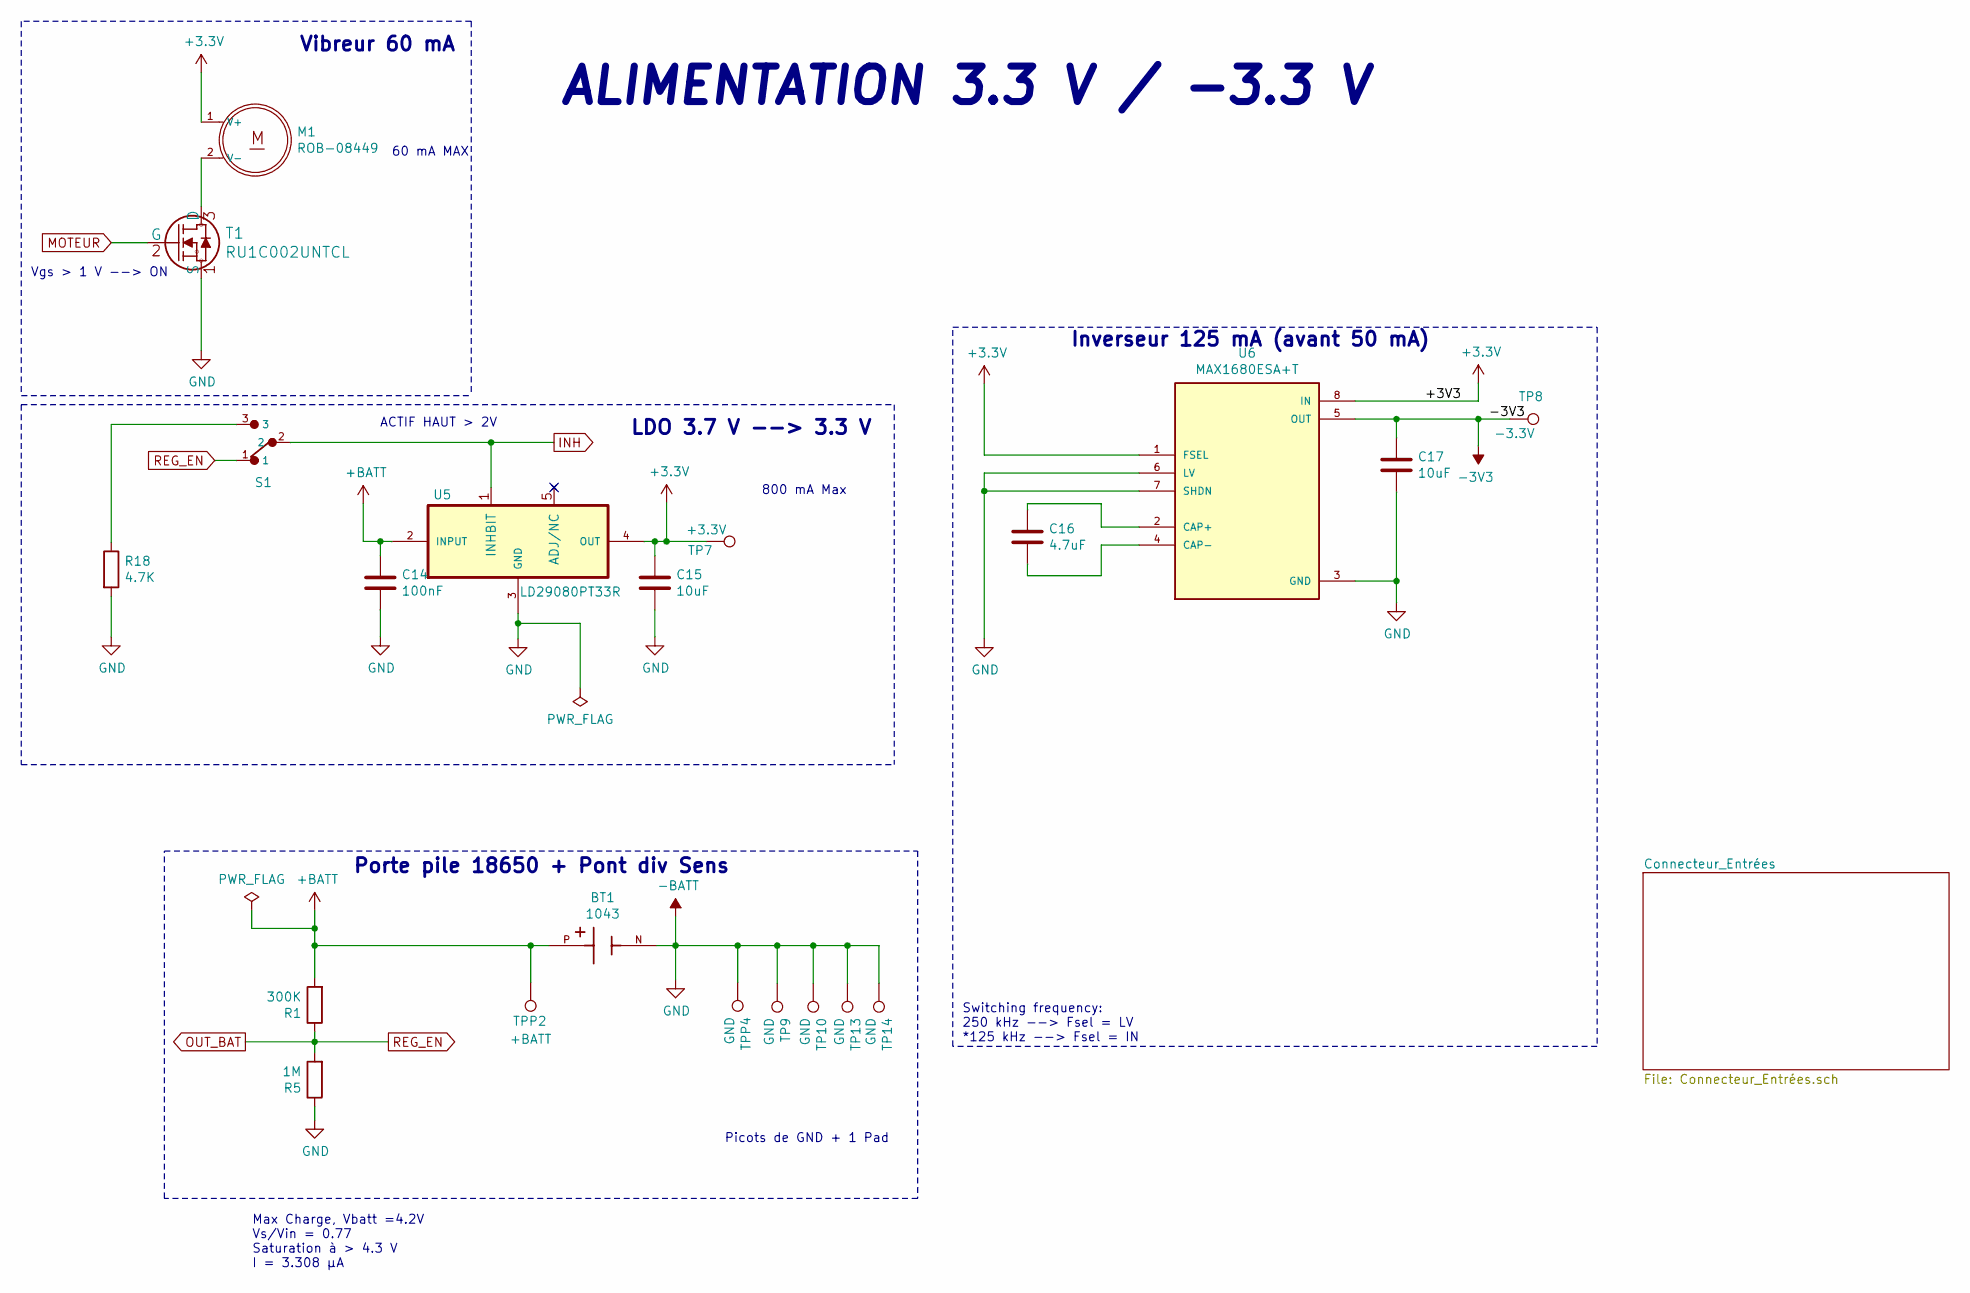
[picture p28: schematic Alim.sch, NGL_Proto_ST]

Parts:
BT1: 1043; BAT_1043; MPN 1043
C14: 100nF; C_0805_2012Metric_Pad1.18x1.45mm_HandSolder
C15, C17: 10uF; C_0805_2012Metric_Pad1.18x1.45mm_HandSolder
C16: 4.7uF; C_0805_2012Metric_Pad1.18x1.45mm_HandSolder
M1: ROB-08449; PinHeader_1x02_P2.54mm_Vertical
R1: 300K; R_0805_2012Metric_Pad1.20x1.40mm_HandSolder
R5: 1M; R_0805_2012Metric_Pad1.20x1.40mm_HandSolder
R18: 4.7K; R_0805_2012Metric_Pad1.20x1.40mm_HandSolder
S1: 1101M2S3CQE2; SW_1101M2S3CQE2
T1: RU1C002UNTCL
TP7: +3.3V; PinHeader_1x01_P2.54mm_Vertical
TP8: -3.3V; PinHeader_1x01_P2.54mm_Vertical
TP9, TP10, TP13, TP14: GND; PinHeader_1x01_P2.54mm_Vertical
TPP2: +BATT; TestPoint_Pad_D3.0mm
TPP4: GND; TestPoint_Pad_4.0x4.0mm
U5: LD29080PT33R; DPAK114P990X239-6N; MPN LF33CDT-TR
U6: MAX1680ESA+T; SOIC127P600X175-8N; PARTREV 0

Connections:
+BATT: BT1.P, C14.1, R1.2, TPP2.1, U5.2 (INPUT)
-3V3: C17.1, TP8.1, U6.5 (OUT); also elsewhere on the board
INH: S1.2, U5.1 (INHBIT); also elsewhere on the board
MOTEUR: T1.2 (G); also elsewhere on the board
unnamed: C16.1, U6.2 (CAP+)
unnamed: C16.2, U6.4 (CAP-)
unnamed: M1.2 (V-), T1.3 (D)
OUT_BAT: R1.1, R5.2, S1.1; also elsewhere on the board

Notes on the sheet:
LDO 3.7 V --> 3.3 V
Porte pile 18650 + Pont div Sens
Inverseur 125 mA (avant 50 mA)
Max Charge, Vbatt =4.2V Vs/Vin = 0.77 Saturation à > 4.3 V I = 3.308 μA
800 mA Max
ALIMENTATION 3.3 V / -3.3 V
60 mA MAX
Vgs > 1 V --> ON
Vibreur 60 mA
ACTIF HAUT > 2V
Switching frequency: 250 kHz --> Fsel = LV *125 kHz --> Fsel = IN
Picots de GND + 1 Pad

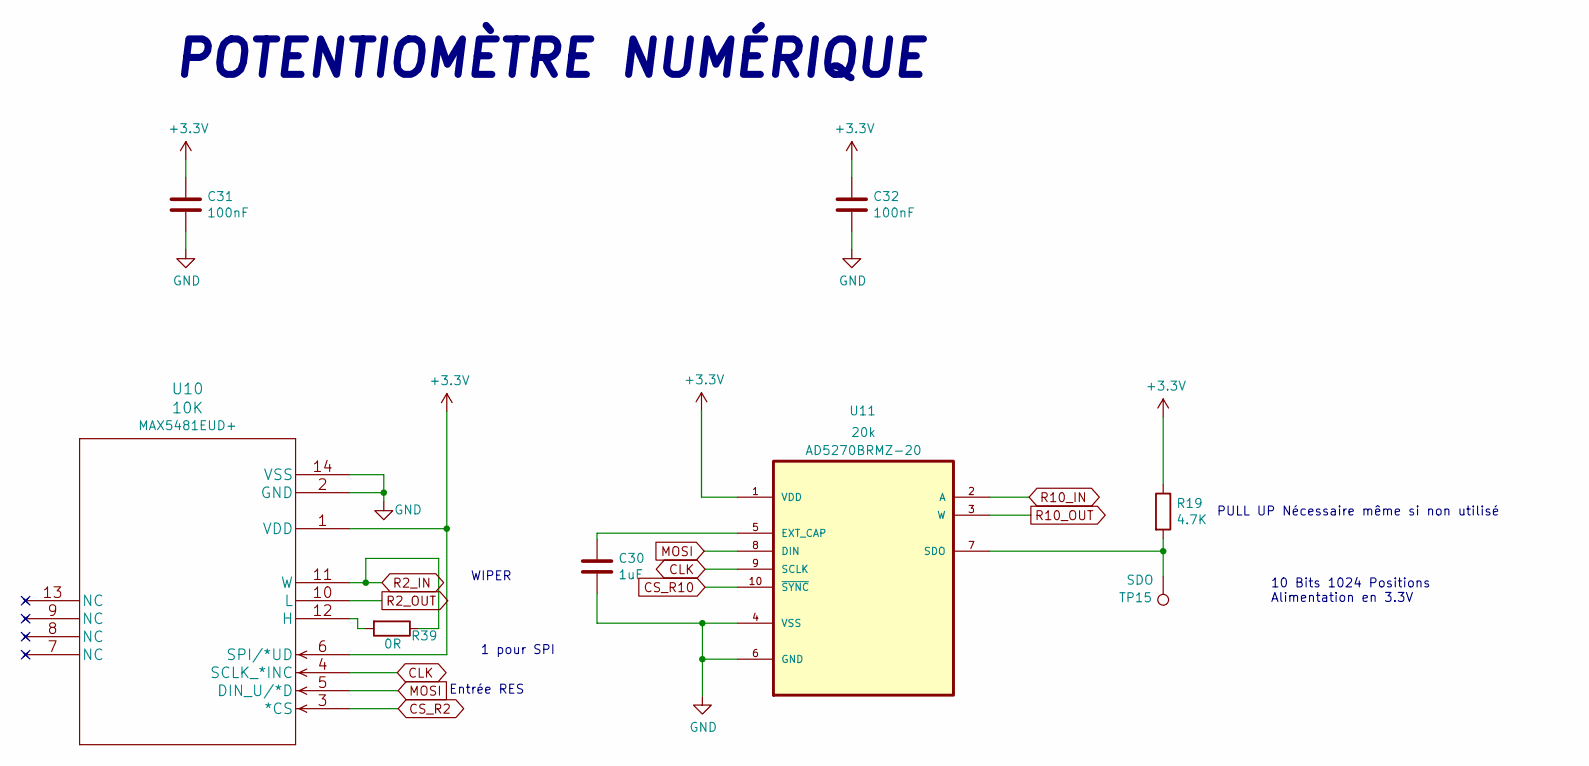
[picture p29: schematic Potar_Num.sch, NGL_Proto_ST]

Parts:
C30: 1uF; C_0805_2012Metric_Pad1.18x1.45mm_HandSolder
C31, C32: 100nF; C_0805_2012Metric_Pad1.18x1.45mm_HandSolder
R19: 4.7K; R_0805_2012Metric_Pad1.20x1.40mm_HandSolder
R39: 0R; R_0805_2012Metric_Pad1.20x1.40mm_HandSolder
TP15: SDO; PinHeader_1x01_P2.54mm_Vertical
U10: 10K; max5481eud&plus_T; MPN MAX5481EUD+
U11: 20k; SOP50P490X110-10N; MPN AD5270BRMZ-20

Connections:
CLK: U10.4 (SCLK_*INC), U11.9 (SCLK); also elsewhere on the board
CS_R2: U10.3 (*CS); also elsewhere on the board
CS_R10: U11.10 (~SYNC); also elsewhere on the board
MOSI: U10.5 (DIN_U/*D), U11.8 (DIN); also elsewhere on the board
unnamed: C30.1, U11.5 (EXT_CAP)
unnamed: R39.2, U10.12 (H)
R2_IN: R39.1, U10.11 (W); also elsewhere on the board
R2_OUT: U10.10 (L); also elsewhere on the board
R10_IN: U11.2 (A); also elsewhere on the board
R10_OUT: U11.3 (W); also elsewhere on the board

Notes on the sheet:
POTENTIOMÈTRE NUMÉRIQUE
10 Bits 1024 Positions Alimentation en 3.3V
Entrée RES
1 pour SPI
PULL UP Nécessaire même si non utilisé
WIPER

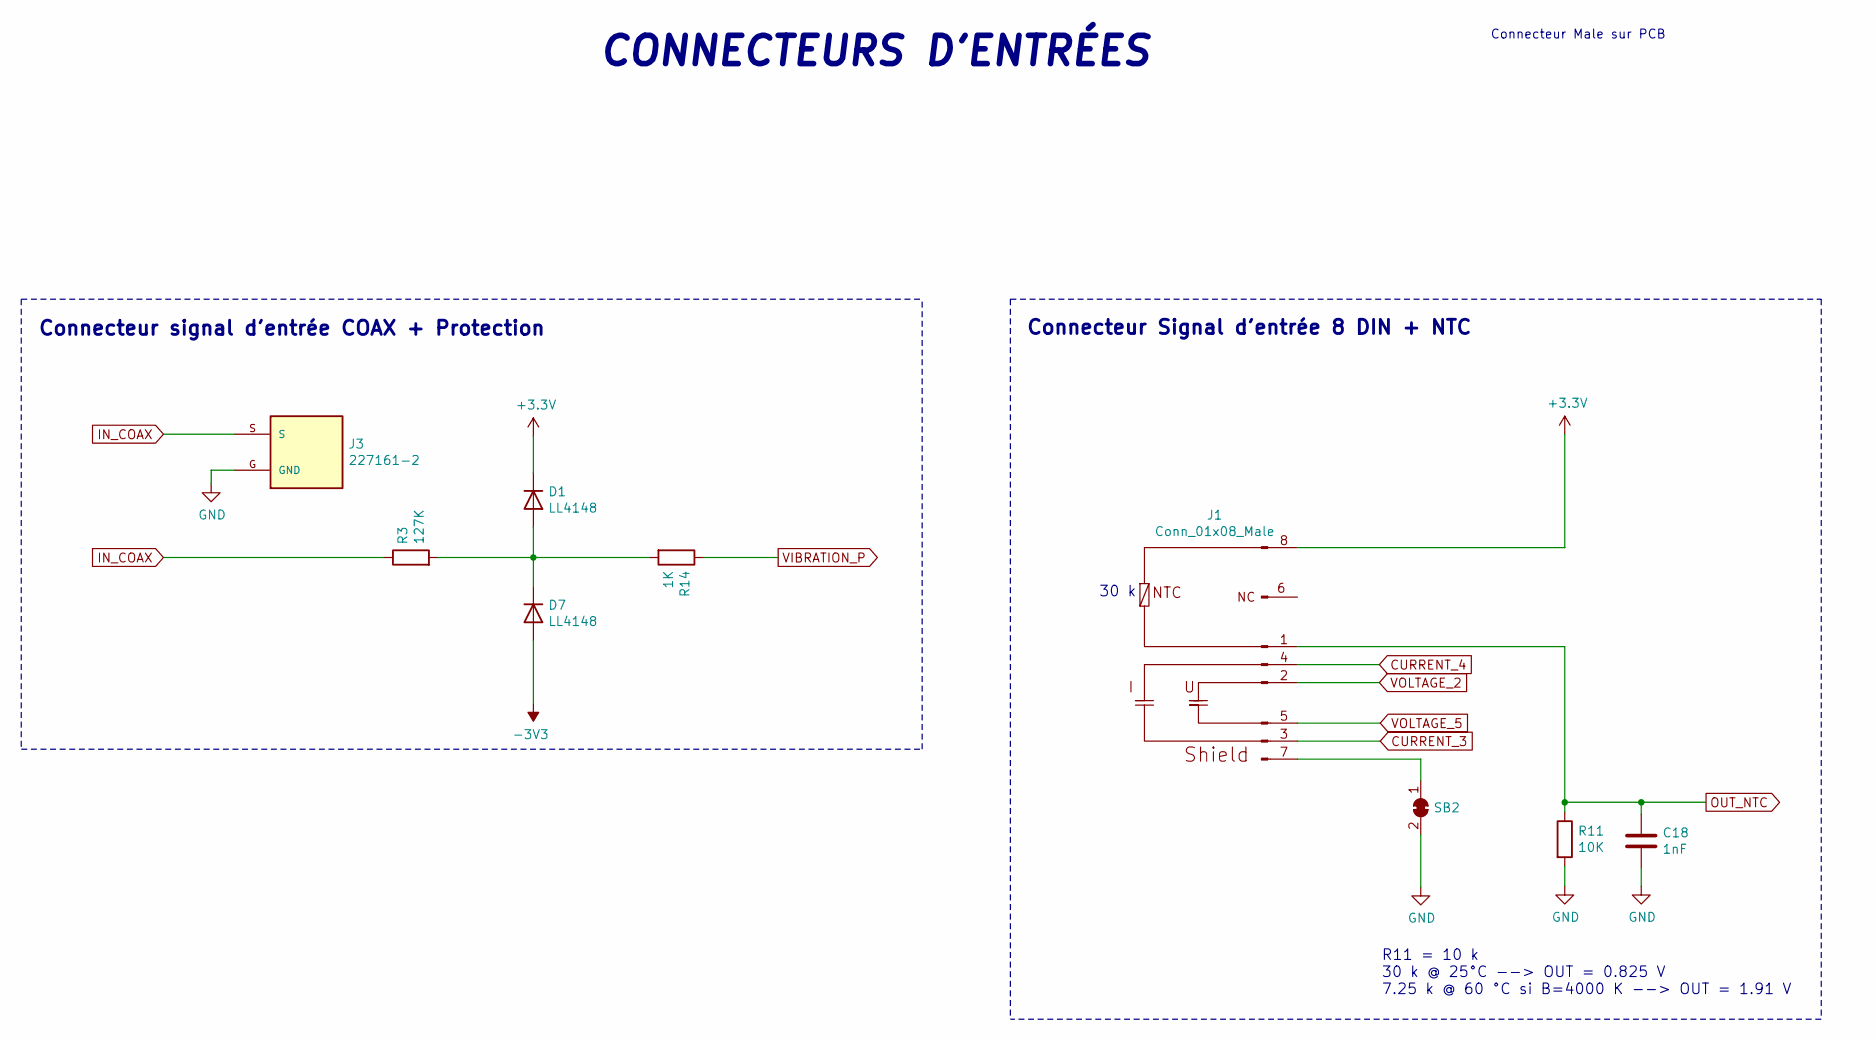
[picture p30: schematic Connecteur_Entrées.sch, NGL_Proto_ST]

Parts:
C18: 1nF; C_0805_2012Metric_Pad1.18x1.45mm_HandSolder
D1, D7: LL4148; D_MiniMELF; MPN LL4148
J1: Conn_01x08_Male; 8DIN_THT
J3: 227161-2; TE_5227161-2; MPN 227161-2
R3: 127K; R_0805_2012Metric_Pad1.20x1.40mm_HandSolder
R11: 10K; R_0805_2012Metric_Pad1.20x1.40mm_HandSolder
R14: 1K; R_0805_2012Metric_Pad1.20x1.40mm_HandSolder
SB2: SolderJumper_2_Bridged; SolderJumper-2_P1.3mm_Open_RoundedPad1.0x1.5mm

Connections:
-3V3: D7.2 (A); also elsewhere on the board
CURRENT_3: J1.3, R14.1; also elsewhere on the board
CURRENT_4: J1.4; also elsewhere on the board
DIFF+: J1.5; also elsewhere on the board
DIFF-: J1.2; also elsewhere on the board
IN_COAX: J3.S, R3.1
unnamed: D1.2 (A), D7.1 (K), R3.2, R14.2
unnamed: J1.7, SB2.1 (A)
OUT_NTC: C18.1, J1.1, R11.1; also elsewhere on the board

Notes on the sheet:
Connecteur Signal d'entrée 8 DIN + NTC
Connecteur signal d'entrée COAX + Protection
Connecteur Male sur PCB
30 k
R11 = 10 k 30 k @ 25°C --> OUT = 0.825 V 7.25 k @ 60 °C si B=4000 K --> OUT = 1.91 V
CONNECTEURS D'ENTRÉES

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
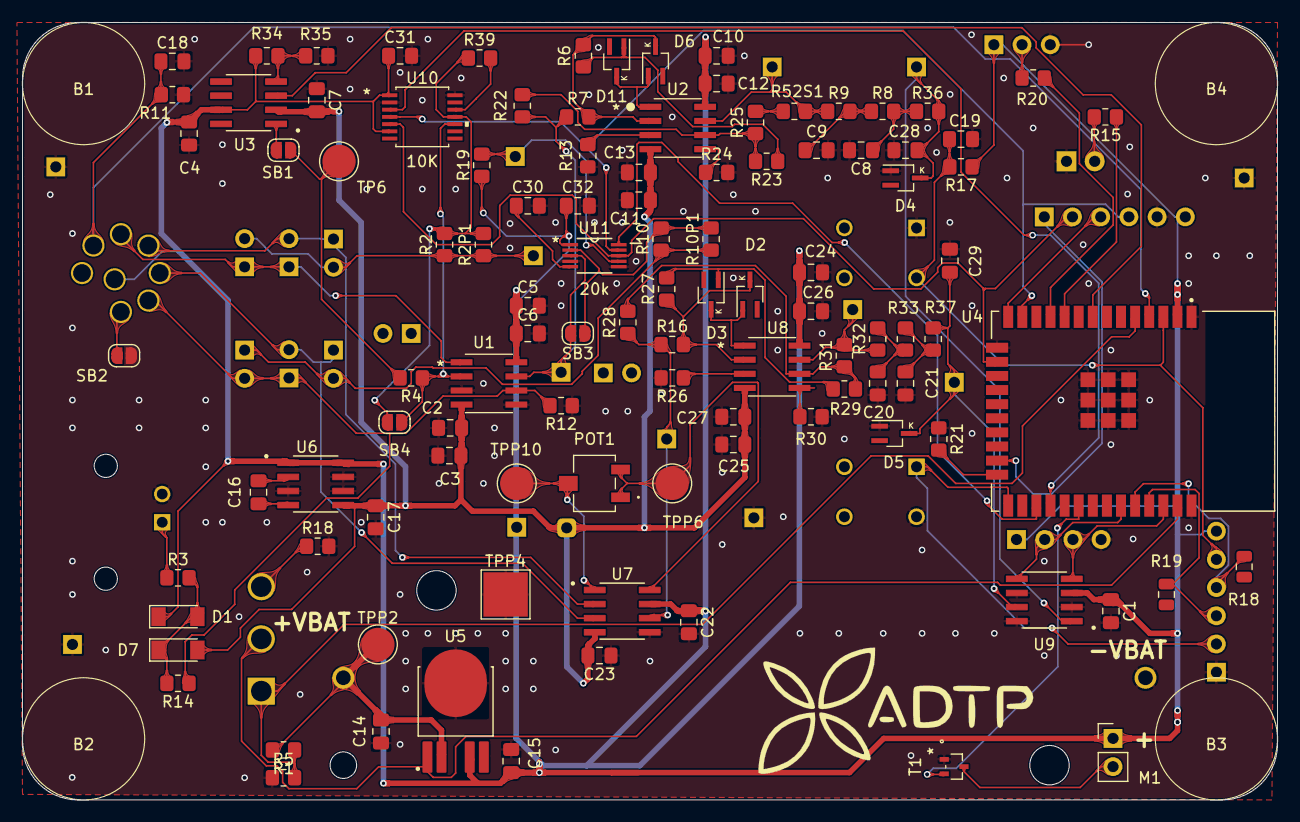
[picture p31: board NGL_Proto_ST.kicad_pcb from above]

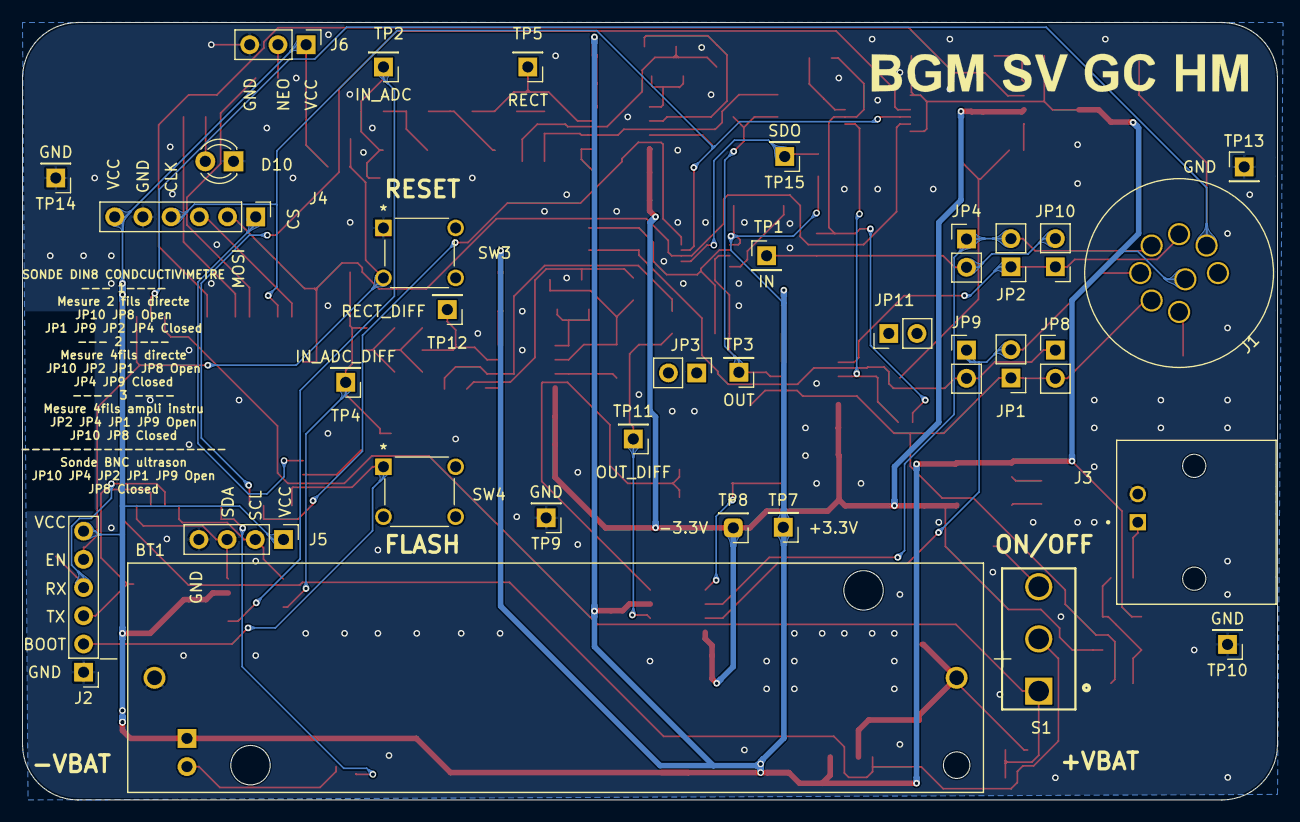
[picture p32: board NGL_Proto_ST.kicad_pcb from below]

Board: 2 copper layers, 113.0 x 70.0 mm, 144 parts (33 on the bottom side), 73 nets.

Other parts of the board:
G1: LOGO; logo_ADTP_Fskils
JP3, JP11: Jumper_NC_Small; PinHeader_1x02_P2.54mm_Vertical
R18#2, R19#2: 4.7K; R_0805_2012Metric_Pad1.20x1.40mm_HandSolder

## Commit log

2022-05-25 Reprise projet au propre
    Il faut ajouter les potar numérique au projet en SPI
    [1043.step, 1101M2S3CQE2.step, 3224X-1-103E.STEP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]
2022-05-26 Rrecherche sur pot num et mise en page
    [AD5270BRMZ-20-RL7.step, Alim.sch, Ampli Diff.sch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]
2022-06-02 amélioration
    [Alim.sch, C0720B001F.step, NGL_Proto_ST.sch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]
2022-06-08 Ajuut nouveaux composants: commande 3
    Attente question ENABL E + POTAR
    [Alim.sch, NGL_Proto_ST.kicad_pcb, NGL_Proto_ST.sch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]
2022-06-08 Avancement après réunion mercredi
    finir pour mettre en review puis attente.
    [Alim.sch, MAX1680ESA_T.step, NGL_Proto_ST.kicad_pcb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]
2022-06-09 Commit avant DSN
    [AD5270BRMZ-20-RL7.step, Alim.sch, Ampli Diff.sch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]
2022-06-09 essai pas mal
    commit avant review
    [NGL_Proto_ST.kicad_pcb]
2022-06-09 REVIEW !!
    [Alim.sch, Ampli Diff.sch, Connecteur_Entrées.sch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]
2022-06-09 Début ajout modifs de la review
    [Alim.sch, Ampli Diff.sch, NGL_Proto_ST.kicad_pcb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]
2022-06-10 Commit avand 2° dsn
    [NGL_Proto_ST.dsn, NGL_Proto_ST.kicad_pcb, esp32.sch]
2022-06-10 avant 3° DSN
    [NGL_Proto_EURO-B_Cu.gbr, NGL_Proto_EURO-F_Cu.gbr, NGL_Proto_EURO-F_Mask.gbr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]
2022-06-10 tut router même masse. Attente sully pour commander
    [NGL_Proto_ST.dsn, NGL_Proto_ST.kicad_pcb]
2022-06-10 Mise sur le NAS pour Sully
    [NGL_Proto_ST.kicad_pcb]
2022-06-10 GERBER généré: PRODUCTION
    EURO
    [NGL_Proto_ST-B_Cu.gbr, NGL_Proto_ST-B_Mask.gbr, NGL_Proto_ST-B_Paste.gbr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]
2022-06-10 Dimensions enlevé PRODUCTION
    [Alim.sch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]
2022-06-10 PRODUCTION après appel Philippe POUTOU
    [NGL_Proto_ST-B_Cu.gbr, NGL_Proto_ST-B_Mask.gbr, NGL_Proto_ST-B_Paste.gbr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]
2022-06-20 BOM généré + ibom
    Check composant
    [NGL_Proto.csv, NGL_Proto_ST.csv]

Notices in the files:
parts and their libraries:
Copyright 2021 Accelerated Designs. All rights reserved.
